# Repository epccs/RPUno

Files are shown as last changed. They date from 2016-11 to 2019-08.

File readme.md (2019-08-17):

# RPUno 

From <https://github.com/epccs/RPUno/>

## Overview

A general purpose ATmega328p controller board with level shift IO and current sources that operate over the wide input voltage range.

The bare metal microcontroller on this board is the same as an Arduino Uno, I use it to evaluate the examples. Normally C is my preference so converting Arduino's C++ into C adds some overhead, the toolchain supports both but find fewer surprises with C. The toolchain is available on most Linux distributions, a Raspberry Pi makes a nice remote computer and can handle networking services robustly. I use SSH to log in to the remote Raspberry Pi and then I can pull updates from GitHub and run the "Makefile" rules that compile and upload the firmware. The mezzanine board [RPUadpt] or [RPUpi] can be used to add a multidrop serial (rpubus). This controller can turn off its shield VIN pin to power down the Raspberry Pi on RPUpi.

[RPUadpt]: https://github.com/epccs/RPUadpt
[RPUpi]: https://github.com/epccs/RPUpi

[Forum](https://rpubus.org/bb/viewforum.php?f=6)

[HackaDay](https://hackaday.io/project/12784-rpuno)

## Status

Note: bootloader speed has changed from 115.2k to 38.4k bps due to upload errors with the new transceiver on RPUpi^4. Command line serial speed was changed to 38.4k bps some time ago. I have no clue how the bootload upload was working.



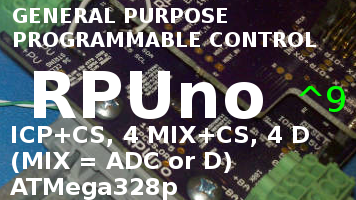
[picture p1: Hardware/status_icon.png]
Status


[Options](./Hardware#bill-of-materials)

## [Hardware](./Hardware)

Hardware files and notes for referance.

## Example with RPU BUS

This example shows a multidrop serial bus that has several microcontroller boards connected to a single Raspberry Pi computer. Linux on the single board computer controls a hardware UART (/dev/ttyAMA0) that has serial lines connected to a transceiver and its differential pairs. The remote boards have a [RPUadpt] mezzanine board and CAT5 cable daisy-chain between them. 

[Irrigate7]: https://github.com/epccs/Irrigate7

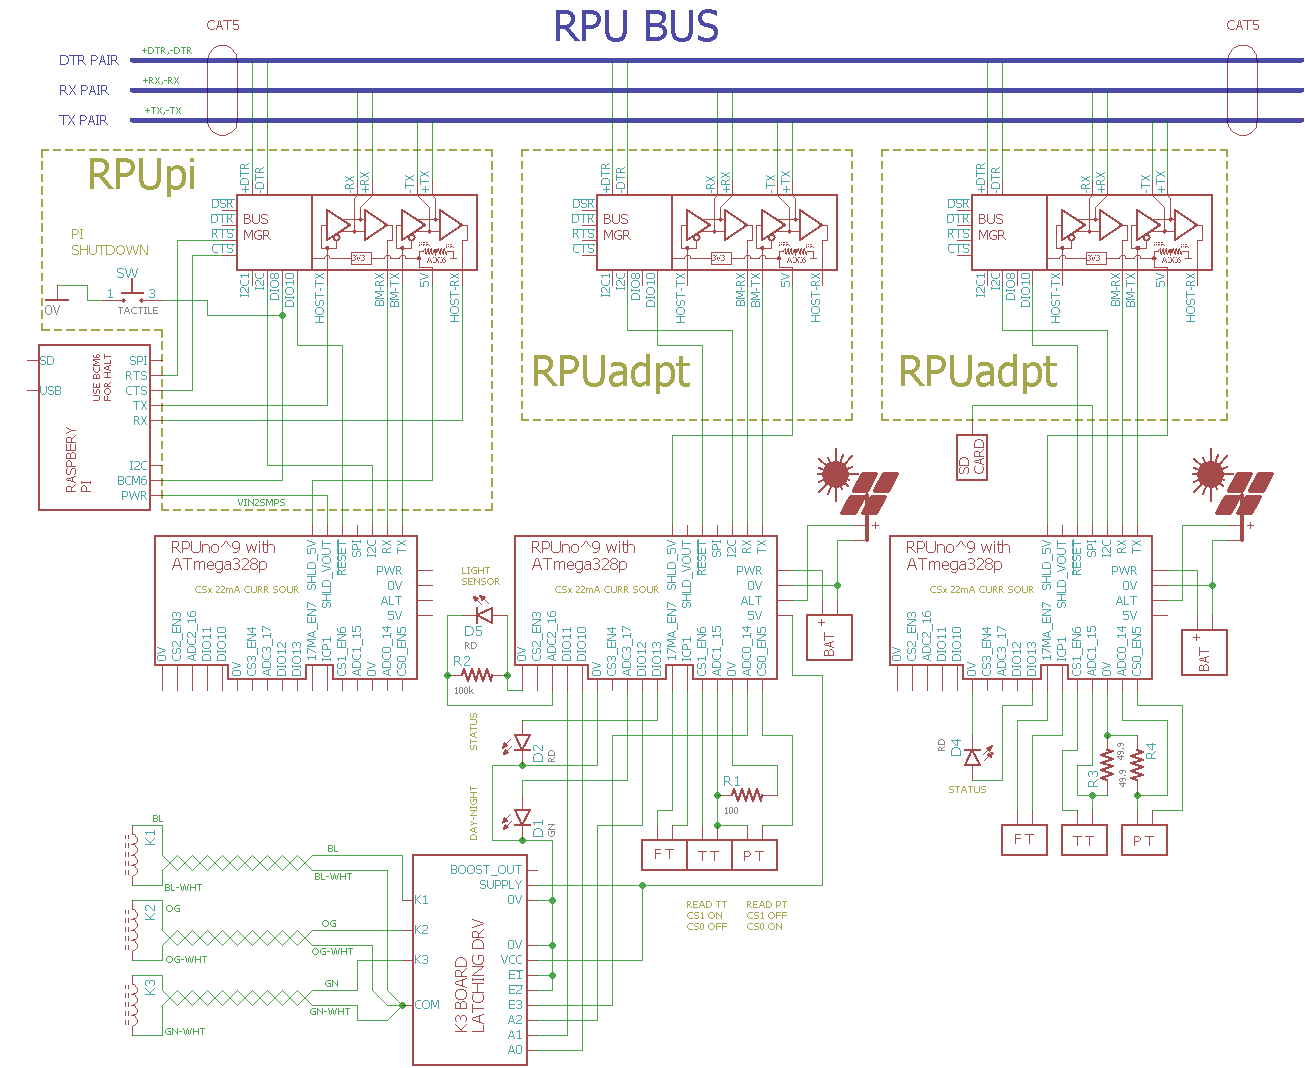
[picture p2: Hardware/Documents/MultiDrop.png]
MultiDrop RPUno MultiDrop


The transceivers are automatically activated, so common serial programs (e.g. avrdude, PySerial, picocom, and UART libraries) work without modification, but care must be taken to ensure only one controller answeres a host command. Each mezzanine board has a bus manager that is used to disconnect all the serial devices when the host connects, only the bootload target controller is connected. The host tells the manager what target to bootload over I2C (either using the local target controller or directly with 328pb second I2C interface). When the target runs its application and reads the bus address over I2C from the manager the manager broadcast a normal mode state that causes all the managers with valid controllers to connect to the serial lines.

I rely on a Command Line Interface (CLI) to the controllers. The CLI responds to commands terminated with a newline (inspired by console), press enter (which sends a newline) to start a command. The command includes an address with the first two bytes, but echo starts after the second byte is sent. The first byte will cause any transmitting device to stop and dump its outgoing buffer which prevents collisions in the data from the controllers to the host. The command length is also limited to allow the use of optimized buffer size.

As a short example, I'll connect with SSH (e.g. from a Windows 1809 build) to a Raspberry Pi Zero board. These machines have matching usernames, with configured SSH keys and known host file from a previous session. Once on the armv61 machine, I use picocom to interact with two different control boards. They are on the same serial bus at addresses '/1' and '/0' (note that ASCII '1' is 0x31, and ASCII '0' is 0x30, so they have an address that looks good on picocom but is probably not what was expected).

```
C:\Users\rsutherland>ssh pi1.local
Linux pi1 4.14.79+ #1159 Sun Nov 4 17:28:08 GMT 2018 armv6l

The programs included with the Debian GNU/Linux system are free software;
the exact distribution terms for each program are described in the
individual files in /usr/share/doc/*/copyright.

Debian GNU/Linux comes with ABSOLUTELY NO WARRANTY, to the extent
permitted by applicable law.
Last login: Sat Feb 16 12:24:59 2019 from 192.168.4.6
rsutherland@pi1:~ $ picocom -b 38400 /dev/ttyAMA0
picocom v1.7

port is        : /dev/ttyAMA0
flowcontrol    : none
baudrate is    : 38400
parity is      : none
databits are   : 8
escape is      : C-a
local echo is  : no
noinit is      : no
noreset is     : no
nolock is      : no
send_cmd is    : sz -vv
receive_cmd is : rz -vv
imap is        :
omap is        :
emap is        : crcrlf,delbs,

Terminal ready
/0/id?
{"id":{"name":"NightLight","desc":"RPUno (14140^9) Board /w atmega328p","avr-gcc":"5.4.0"}}
/1/id?
{"id":{"name":"AmpHr","desc":"RPUlux (17323^2) Board /w atmega328p","avr-gcc":"5.4.0"}}
Ctrl-a,Ctrl-x 
Thanks for using picocom
rsutherland@pi1:~ $ exit
logout
Connection to pi1.local closed.

C:\Users\rsutherland>
```

At present, I'm using [I2Cdebug] to set the manager bootload address. 

[I2Cdebug]: ./i2c-debug

## AVR toolchain

The core files for this board are in the /lib folder. Each example has its files and a Makefile in its own folder. The toolchain packages that I use are available on Ubuntu and Raspbian. 

```
sudo apt-get install make git gcc-avr binutils-avr gdb-avr avr-libc avrdude
git clone https://github.com/epccs/RPUno
```

packages on ubuntu are from Debain

* [gcc-avr](https://packages.ubuntu.com/search?keywords=gcc-avr)
* [binutils-avr](https://packages.ubuntu.com/search?keywords=binutils-avr)
* [gdb-avr](https://packages.ubuntu.com/search?keywords=gdb-avr)
* [avr-libc](https://packages.ubuntu.com/search?keywords=avr-libc)
* [avrdude](https://packages.ubuntu.com/search?keywords=avrdude)

The repository of binutils-avr for Debian is at

https://salsa.debian.org/debian/binutils-avr

The upstream where it was started from is 

https://www.gnu.org/software/binutils/

I don't see any AVR stuff in the upstream. Atmel must have forked it, and Debian is just patching critical material on the fork. Sadly I get the idea that these build tools are the last thing Microchip wants to mess with, I do not blame them it is a cluster, but it could be improved if they would start a public Github or Gitlab repository for these tools so I could have a place to contribute. Ideally, these updates would be added to the upstream, but I suspect that is not practical. Arduino uses these tools also, but they mainly want responsibility for there IDE. 

I place a [Bootloader] on the bare metal microcontroller with a fuse step and a step that uploads using an ISP tool. 

[Bootloader]: https://github.com/epccs/RPUno/tree/master/Bootloader

```
cd RPUno/Bootloader
# note /dev/ttyACM0 is my ICSP tool.
make fuse
make isp
```

The other applications are loaded through the bootloader using the host serial port. Note that the fuse cannot be changed with the bootloader thus reducing user issues with an application upload.

```
cd ~/RPUno/Adc
# note /dev/ttyUSB0 is my FTDI USBuart, and /dev/ttyAMA0 is my Raspberry Pi
make bootload
```

The software is a guide, it is in C because that is my preference for microcontrollers. If you want additional software please add a Github issue to this repository where we can discuss it. 

## Continuous Integration

Continuous Integration (CI) is the practice of automatically compiling and testing each time the mainline source is updated (e.g. git push). Travis CI is using a version of Ubuntu as there host environment for doing the test build. The build machine allows pulling in any packages I want including the AVR cross compiler. I don't do anything fancy, just run make. A rule like "make test" could be used if the test build machine had hardware connected (e.g. "make bootload" and then "make test") to the machine, but that is not practical in the foreseeable future. This was fairly simple to set up for Travis because the ATmega328p was in production at the time the Ubuntu toolchain was done.

[https://travis-ci.org/epccs/RPUno](https://travis-ci.org/epccs/RPUno)

Update: Travis has Ubuntu [Xenial] 16.04.

[Xenial]: https://docs.travis-ci.com/user/reference/xenial/

## Arduino IDE with Arduino 328p Core

The Arduino [IDE] can use the [Uno's AVR core] files that are included (my [core] files are C rather than C++), just remember to look at the schematic to see how the "Uno" is connected.  I do not use the Arduino IDE or C++ (I am a hardware designer,.and have limited intrest in software).

[IDE]: https://www.arduino.cc/
[Uno's AVR core]: https://github.com/arduino/ArduinoCore-avr
[core]: https://github.com/epccs/RPUno/tree/master/lib

## Visual Studio Code

VSC is one of the editors I use, and it is happy with Makefiles. The feature I like most is [IntelliSense], which is configured with JSON files in [.vscode]. 

[IntelliSense]: https://code.visualstudio.com/docs/editor/intellisense
[.vscode]: https://github.com/epccs/RPUno/tree/master/.vscode

The best way to use VSC with GCC (avr-gcc) is in an environment that just works, for me that is Linux, so I can enable [WSL] and install Ubuntu and then use the [Remote WSL].

[WSL]: https://docs.microsoft.com/en-us/windows/wsl/install-win10
[Remote WSL]: https://code.visualstudio.com/docs/remote/wsl

or I can install Linux on a 64bit x86 machine and use [Remote SSH].

[Remote SSH]: https://code.visualstudio.com/docs/remote/ssh

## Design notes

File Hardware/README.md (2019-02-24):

# Hardware

## Overview

ATmega328p based controller board with options for DIN mounts and 3.5mm spaced through-hole for user connections and headers. Eight level shifted (same as VIN range) digital I/O (10, 11, 12, 13, 14*, 15*, 16*, 17*), the last four (*) are analog channels (0, 1, 2, 3). Four 22mA current source used with loop sensors are available with enables (5, 6, 3, 4). One 17mA current source for a pulse sensor and it has an enable (7). ICP1 is pulled down when enough current (>7mA) arrives from the pulse sensor. Alternate power input may be enabled (9), and power to the shield VIN pin may be disabled (2). Power with 7 thru 36V DC.

The ATmega328p can be programmed with the GCC based toolchain for AVR found in Debian packages (it is available on, Ubuntu, Raspbian, Mac via brew, Windows via Windows Subsystem for Linux). Bootloader options include [optiboot] and [xboot]. Serial bootloaders cannot change the hardware fuse setting which reduces the occurrence of accidentally bricking the controller (I recommend using a serial bootloader during application development). Note that [optiboot] clears the watchdog so it will not get stuck in a watchdog loop.

[optiboot]: https://github.com/Optiboot/optiboot
[xboot]: https://github.com/alexforencich/xboot

## Inputs/Outputs/Functions

```
        Toolchain: gcc-avr binutils-avr gdb-avr avr-libc avrdude
        Wide input power range from 7..36V DC
        High side current sense on input power connected to ADC6.
        Input power voltage is divided down and connected to ADC7.
        Eight digital input/outputs (10,11,12,13,14*,15*,16*,17*) with level conversion.
        Four of the DIO may be used for ADC (*) channels 0..3 (ADC0,ADC1,ADC2,ADC3)
        Four 22mA current sources with enable (3,4,5,6).
        One 17mA current source with enable (7).
        Power to the shield VIN pin may be disabled (2).
        Alternate power input may be enabled (9).
        MCU power (+5V) is converted with an SMPS from the 7..36V input power.
```

## Uses

```
        General Purpose Control for Automation
            Bare Matal (e.g. infinite main loop checks inputs, performs algorithm, and writes outputs)
        Data Acquisition using Capture Hardware (ICP1).
            Flow Meter
            Rotating Hardware
            Pulse Output Temperature Sensors
            Pulse Output Capacitance Sensors
        Automation
            Shield VIN pin can power down a Raspberry Pi on the RPUpi shield.
            A current source may string through inputs of multiple Solid State Relays to control multi-phase power.
            Program in C with an open source toolchain (e.g. GCC, avrdude...).
```

## Notice

```
        ADC4 and ADC5 are used for I2C exclusively and not routed to the analog header.
        AREF from ATmega328p is not routed to the header.
        3V3 is not present on the board, the header pin is not connected.
```

# Table Of Contents

1. [Status](#status)
2. [Design](#design)
3. [Bill of Materials](#bill-of-materials)
4. [Assembly](#assembly)
5. [How To Use](#how-to-use)

# Status

Status RPUno Status

```
        ^9  Done: Design, Layout, BOM, Review*, Order Boards, Assembly, Testing,
            WIP: Evaluation.
            Todo: 
            *during review the Design may change without changing the revision.
            Remove ICP1 10mA pull-up
            Replace digital curr sources with CS2 and CS3
            Replace IO3 and IO4 with ADC2 and ADC3
            Swap MOSI (IO11) with ADC3
            Use IO3 and IO4 to enalbe 22mA CS2 and CS3
            Add level shift to ADC0 and ADC1 so they can be used as digital IO
            Add bootload port (e.g. for Adafruit Friend)
            Add alternate power input (e.g. disconnect a solar pannel to stop charge)
            Pull-down IO9 and 100k ohm on zener to make sure alt power is off at init

        ^8  Done: Design, Layout, BOM, Review*, Order Boards,
            all boards scraped, no assembly done

        ^7  Done: Design, Layout, BOM, Review*, Order Boards, Assembly, Testing,
            WIP: Evaluation.
            use an ESD_NODE like Irrigate7.
            don't turn off the current source used with digital outputs since the digital IO's can do that. 
            DIO protection resistor (change 182 Ohm to 127 Ohm)
            remove LT3652 and reduce size of board.
            add an IDC connector for everything that was used with LT3652 (5,6,7,ADC2,ADC3).
            add JSK plug for I2C
            location: 2017-11-1 reflow oven.

        ^6  two test units (T1,T2) made, four units made to see if anyone is intrested.
            location: 2017-3-24 T1^6 damaged MCU while taking power example image.
                    2017-3-25 T2^6 using on test bench.
                    2017-6-12 T1^6 replaced MCU from a scrped RPUno^4 and tested again.
                    2017-7-19 T2^6 + RPUadpt^5 in SEncl NightLight testing.
                    2017-8-26 T2^6 NightLight ended, unit is in an enclosure with battey but is not in use.
                    2018-4-15 T1 and T2 scap.

        ^5  only unit of this version made
            location: 2016-12-18 Test Bench /w an RPUpi^1, start power management testing
                    2017-1-1 had ADC7 parts (and BOM) changed to measre battery.
                    2017-1-5 had ADC6 hacked to measure raw PV.
                    2017-2-4 moved to SWall Encl /w K3^1, RPUadpt^4, SLP003-12U, 12V battery.
                    2017-3-19 remove 10k thermistor which was used by  LT3652 to turn off chrg when over 40 C
                    2017-4-17 running Solenoid fw, @ SWall Encl, Update K3^2, Update RPUadpt^5, SLP003-12U, 12V battery.
```

Debugging and fixing problems i.e. [Schooling](./Schooling/)

Setup and methods used for [Evaluation](./Evaluation/)

# Design

The board is 0.063 thick, FR4, two layer, 1 oz copper with ENIG (gold) finish.

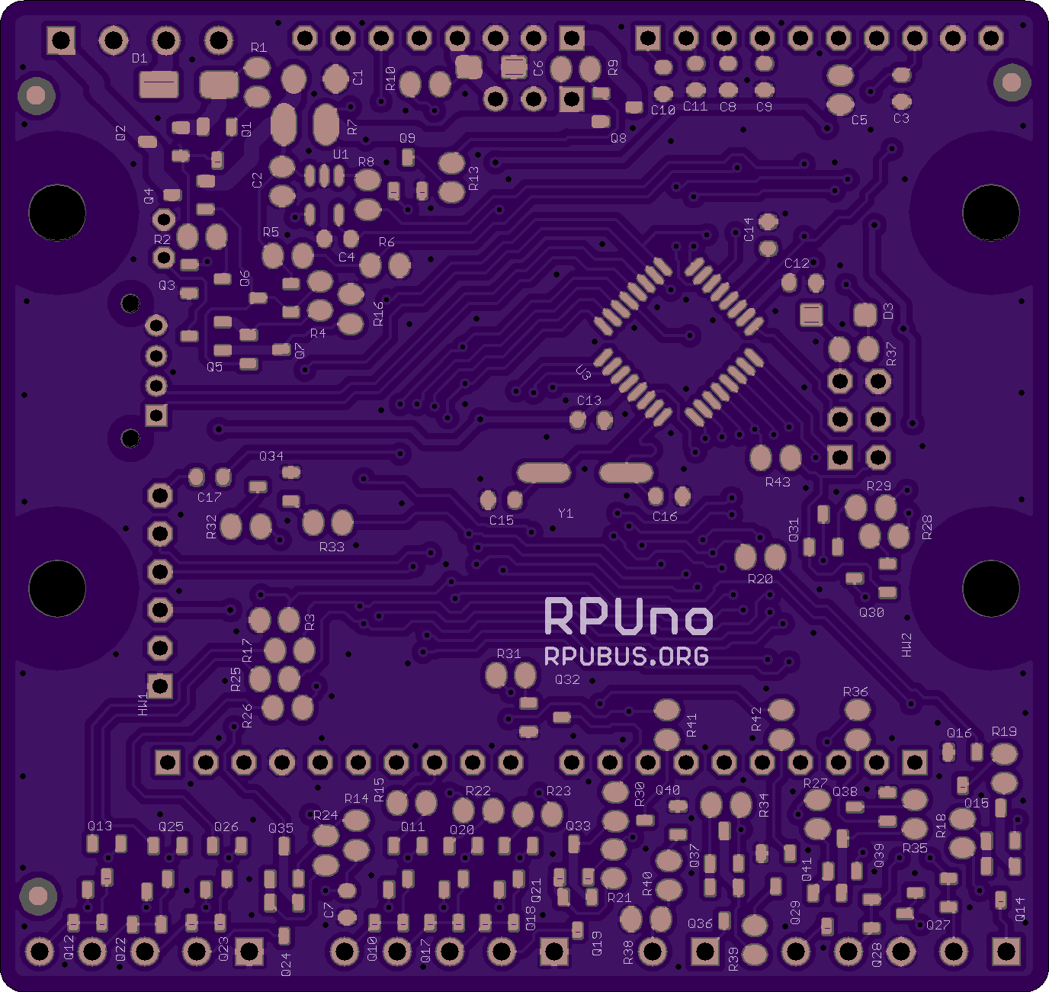
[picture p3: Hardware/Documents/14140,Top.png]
Top RPUno Top

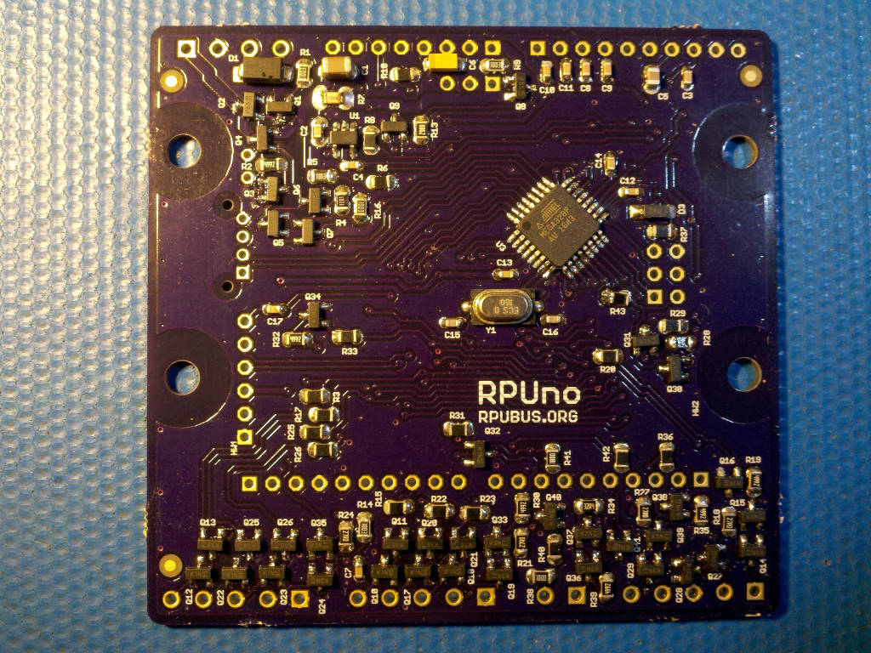
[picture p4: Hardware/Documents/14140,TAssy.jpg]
TAssy RPUno Top Assy

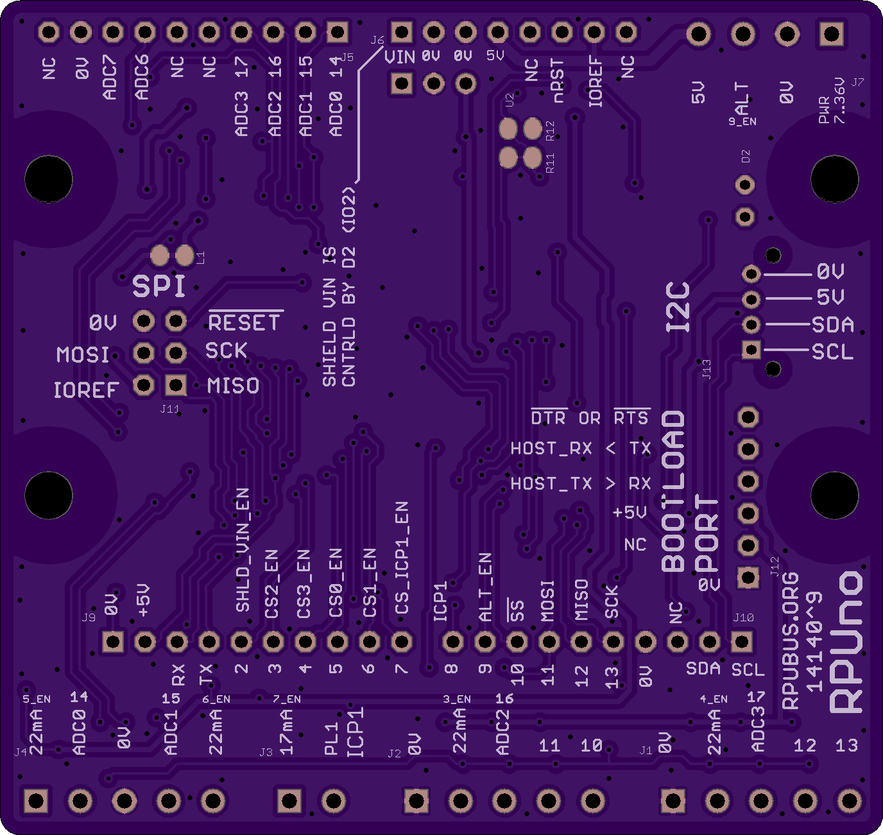
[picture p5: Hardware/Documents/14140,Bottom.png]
Bottom RPUno Bottom

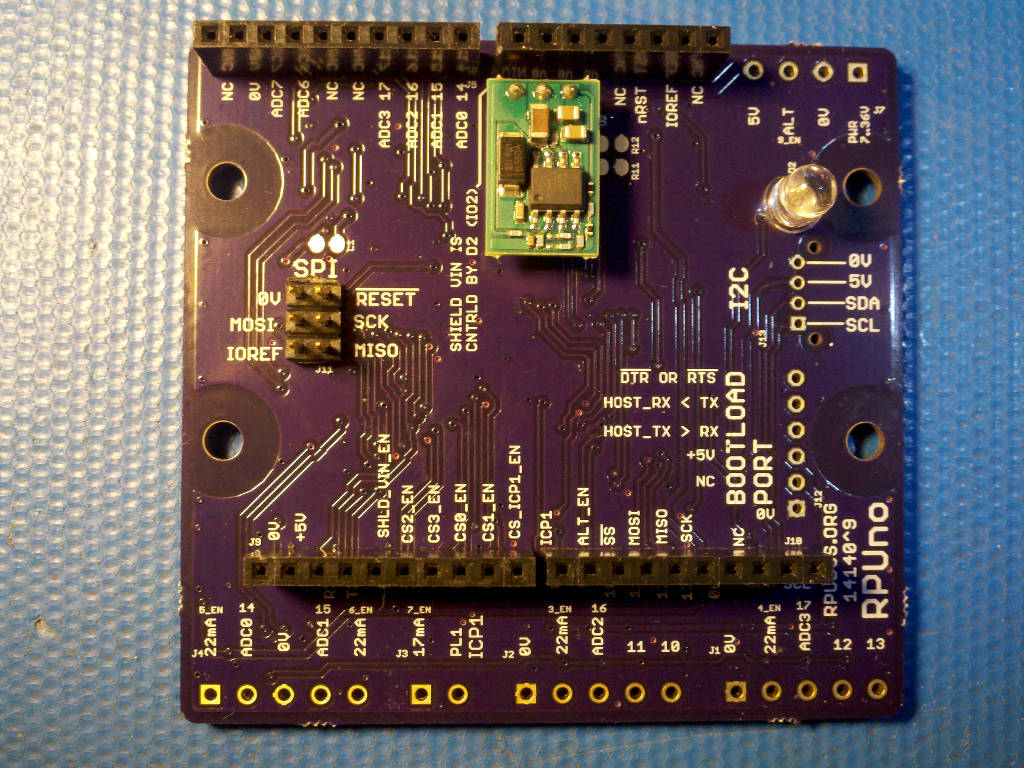
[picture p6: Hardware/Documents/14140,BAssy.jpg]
BAssy RPUno Bottom Assy


## Electrical Parameters

```
Power Voltage: 7 thru 36V
```

## Mounting

```
        DIN rail
```

## Electrical Schematic

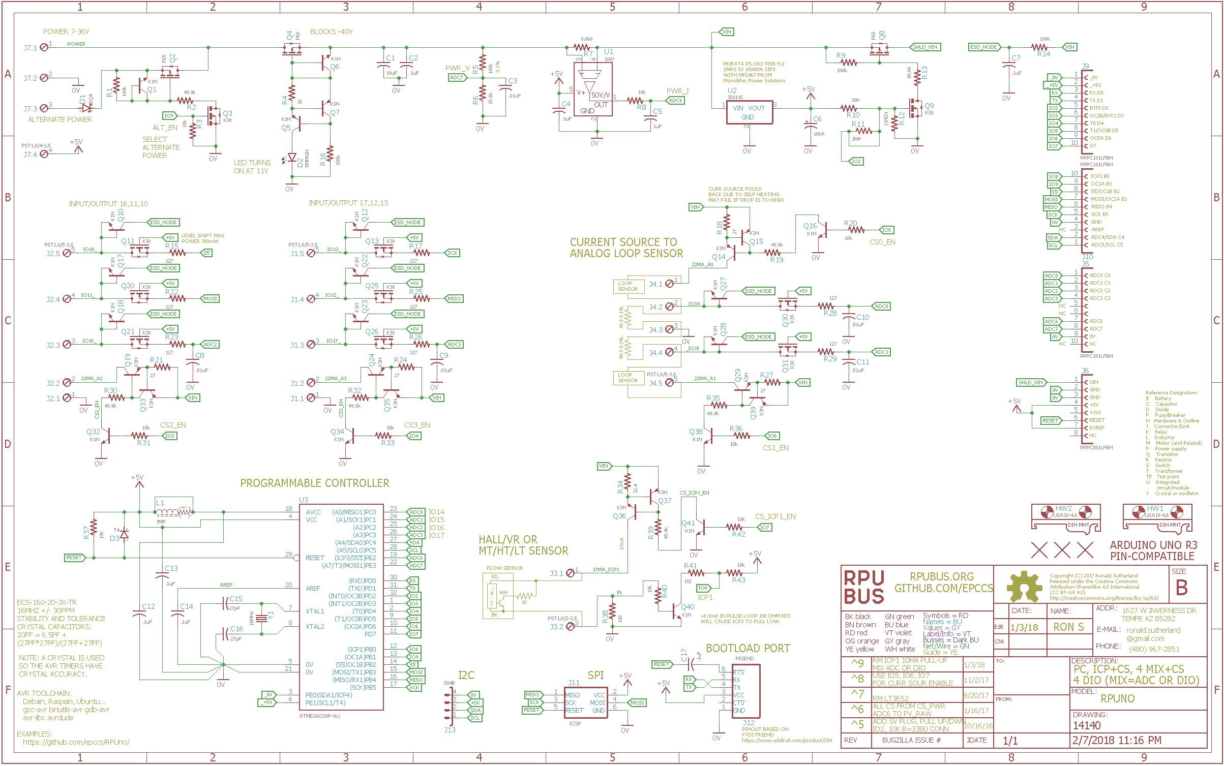
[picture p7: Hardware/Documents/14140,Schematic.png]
Schematic RPUno Schematic


## Testing

Check correct assembly and function with [Testing](./Testing/)

# Bill of Materials

The BOM is a CVS file, import it into a spreadsheet program like LibreOffice Calc (or Excel), or use a text editor.

Option | BOM's included
----- | ----- 
A. | [BRD] 
M. | [BRD] [SMD] [HDR] 
W. | [BRD] [SMD] [HDR] [PLUG]
Z. | [BRD] [SMD] [HDR] [PLUG] [DIN]

[BRD]: ./Design/14140BRD,BOM.csv
[SMD]: ./Design/14140SMD,BOM.csv
[HDR]: ./Design/14140HDR,BOM.csv
[PLUG]: ./Design/14140PLUG,BOM.csv
[DIN]: ./Design/14140DIN,BOM.csv

[Order Form](https://rpubus.org/Order_Form.html)

# Assembly

## SMD

The board is assembled with CHIPQUIK no-clean solder SMD291AX (RoHS non-compliant). 

The SMD reflow is done in a Black & Decker Model NO. TO1303SB which has the heating elements controlled by a Solid State Relay and an ATMega328p loaded with this [Reflow] firmware.

[Reflow]: https://github.com/epccs/RPUno/tree/master/Reflow

# How To Use

The application should have a wiring diagram to show the setup.

## Solar

Trickle charging a battery can be done directly through a diode when the PV source is less than or about .02C (e.g. 200mA into a 10AHr battery). This means that the need for a charge controller depends on if the user wants to size the PV and battery storage for trickle or quick charging (i.e. >0.02C). When I use an SLP003-12U panel that charges at less than 200mA and a 10AHr AGM battery with a diode that blocks dark current no charge controller is needed. 

## Input Power LC 

Input wiring can have inductance that oscilates as an [LC circuit] with the input capacitor. The problem can show up when the SMPS has a frequancy component that drives the oscilation. There are many ways to deal with the issue, a few examples include twisting the input power wires to lower there inductance, adding a ferite to dampen the oscilation, adding a bypass or two along the line to shift the oscilation nodes.

[LC circuit]: https://en.wikipedia.org/wiki/LC_circuit

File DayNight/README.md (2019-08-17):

# Day-Night State Machine

## Overview

Use a red LED's photovoltaic voltage to approximately tell if it is day or night. 

Note: use the Day_AttachDayWork() and Night_AttachWork() functions to register a callback that will be run at the start of each day. This framework is how I debuged the day-night stat machine.

## Wiring Needed for Light Sensor

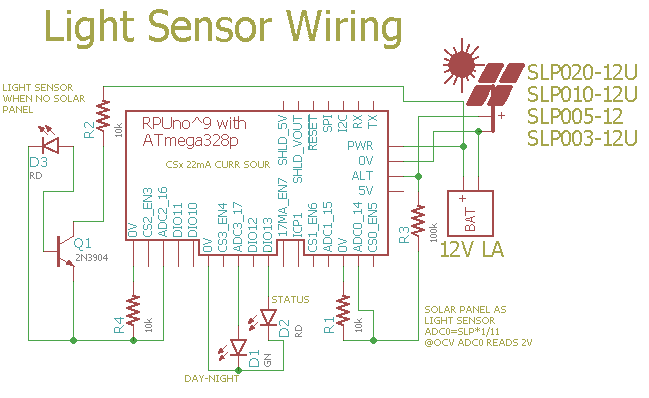
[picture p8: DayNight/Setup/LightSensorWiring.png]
Wiring


The LED is a CREE C503B-RCN-CW0Z0AA1. The LED works somewhat like a solar cell but it develops up to 1.6V with red light and shorter wavelengths. The LED will act as a current source to the NPN transistor base which will then do [common emitter current gain] which can be measured with ADC1 on R4. Over a very short time, the sun will move through the LED focus. Adding a diffuser reduces this effect and extends the day/night debounce to more appropriate times.

[common emitter current gain]: https://en.wikipedia.org/wiki/Bipolar_junction_transistor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

With a solar panel use a [voltage divider].

[voltage divider]: https://en.wikipedia.org/wiki/Voltage_divider

## Firmware Upload

With a serial port connection (see BOOTLOAD_PORT in Makefile) and optiboot installed on the RPUno run 'make bootload' and it should compile and then flash the MCU.

``` 
sudo apt-get install make git gcc-avr binutils-avr gdb-avr avr-libc avrdude
git clone https://github.com/epccs/RPUno/
cd /RPUno/DayNight
make bootload
...
avrdude done.  Thank you.
``` 

Now connect with picocom (or ilk). 

``` 
#exit is C-a, C-x
picocom -b 38400 /dev/ttyUSB0
``` 

# Commands

Commands are interactive over the serial interface at 38400 baud rate. The echo will start after the second character of a new line. 

## /\[rpu_address\]/\[command \[arg\]\]

rpu_address is taken from the I2C address 0x29 (e.g. ../Uart/id.h get_Rpu_address() ). The value of rpu_address is used as a character in a string, which means don't use a null value (C strings are null terminated), but the ASCII value for '1' (0x31) is easy and looks nice.

The STATUS_LED is bliked fast (twice per second) if the I2C address is not found, also the rpu_address defaults to '0'. 

Commands and their arguments follow.

## /0/id? \[name|desc|avr-gcc\]

Identify is from ../Uart/id.h Id().

``` 
/1/id?
{"id":{"name":"DayNight","desc":"RPUno Board /w atmega328p and LT3652","avr-gcc":"4.9"}}
```

## /0/day?

Report status of the state machine.

``` 
/1/day?
{"day_state":"DAY"}
... 11 hr
{"day_state":"DAY"}
{"day_state":"EVE"}
... 15 min
{"day_state":"NEVT"}
TurnOnLED's
{"day_state":"NGHT"}
... 12 hr
{"day_state":"NGHT"}
{"day_state":"MORN"}
... 15 min
{"day_state":"DEVT"}
WaterTheGarden
{"day_state":"DAY"}
... 20 hr (e.g. using an indoor lamp)
{"day_state":"DAY"}
{"day_state":"FAIL"}
```

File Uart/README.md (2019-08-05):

# AVR Interrupt-Driven UART with stdio redirect

## Overview

Uart is an interactive command line program that demonstrates stdio redirect of a minimalized interrupt-driven UART for AVR. 

## Firmware Upload

With a serial port connection (see BOOTLOAD_PORT in Makefile) and optiboot installed on the RPUno run 'make bootload' and it should compile and then flash the MCU.

``` 
sudo apt-get install make git gcc-avr binutils-avr gdb-avr avr-libc avrdude
git clone https://github.com/epccs/RPUno/
cd /RPUno/Uart
make bootload
...
avrdude done.  Thank you.
``` 

Now connect with picocom (or ilk).

``` 
#exit is C-a, C-x
picocom -b 38400 /dev/ttyUSB0
``` 

# Commands

Commands are interactive over the serial interface at 38400 baud rate. The echo will start after the second character of a new line. 

## /\[rpu_address\]/\[command \[arg\]\]

rpu_address is taken from the I2C address 0x29 (e.g. get_Rpu_address() which is included form ../lib/rpu_mgr.h). The value of rpu_address is used as a character in a string, which means don't use a null value (C strings are null terminated) as an adddress. The ASCII value for '1' (0x31) is easy and looks nice, though I fear it will cause some confusion when it is discovered that the actual address value is 49.

Commands and their arguments follow.

## /0/id? \[name|desc|avr-gcc\]

identify 

``` 
/0/id?
{"id":{"name":"Uart","desc":"RPUno Board /w ATmega328p and LT3652","avr-gcc":"4.9"}}
```

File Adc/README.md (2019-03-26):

# Analog-to-Digital Converter

## Overview

Adc is an interactive command line program that demonstrates control of an Analog-to-Digital Converter from pins PC0 through PC7 on an ATmega328p. 

A customized library routine is used to operate the AVR's ADC, it has an ISR that is started with the enable_ADC_auto_conversion function to read the channels in a burst (free running is also an option). In this case, the bare metal loop starts the burst at timed intervals of 200 milliseconds. The ADC clock runs at 125kHz and it takes 25 of its clocks to complete a conversion, thus a burst takes 1.6 milliseconds (e.g. 8*25*(1/125000)) to scan the eight channels. The ADC is turned off after each burst so some power is saved, but barely enough to bother.

The ADMUX register is used when selecting ADC channels.  The analog channel has nothing to do with the digital pin number used by [Wiring]. The pin used by ADC channel 0 has been assigned the number 14 for the digital Wiring functions (e.g. pinMod, digitalRead...), however for analogRead the ADC channel number is used.

[Wiring]: https://arduinohistory.github.io/

# EEPROM Memory map 

A map of calibration valuses in EEPROM. 

```
function            type        ee_addr:
id                  UINT16      30
ref_extern_avcc     UINT32      32
ref_intern_1v1      UINT32      36
```

The AVCC pin is used to power the analog to digital converter and is also selected as a reference. On RPUno the AVCC pin is powered by a switchmode supply that can be measured to use as a calibrated reference.

The internal 1V1 bandgap is not trimmed by the manufacturer, so it needs to be measured. However, once it is known it is a better reference than AVCC.

[SelfTest] loads calibration values for references in EEPROM.

[SelfTest]: https://github.com/epccs/RPUno/tree/master/SelfTest

# Firmware Upload

With a serial port connection (see BOOTLOAD_PORT in Makefile) and optiboot installed on the RPUno run 'make bootload' and it should compile and then flash the MCU.

``` 
sudo apt-get install make git gcc-avr binutils-avr gdb-avr avr-libc avrdude
git clone https://github.com/epccs/RPUno/
cd /RPUno/Adc
make bootload
...
avrdude done.  Thank you.
``` 

Now connect with picocom (or ilk).

``` 
#exit is C-a, C-x
picocom -b 38400 /dev/ttyUSB0
``` 

or log the terminal session

``` 
script -f -c "picocom -b 38400 /dev/ttyUSB0" stuff.log
``` 

# Commands

Commands are interactive over the serial interface at 38400 baud rate. The echo will start after the second character of a new line. 

## /\[rpu_address\]/\[command \[arg\]\]

rpu_address is taken from the I2C address 0x29 (e.g. get_Rpu_address() which is included form ../lib/rpu_mgr.h). The value of rpu_address is used as a character in a string, which means don't use a null value (C strings are null terminated) as an adddress. The ASCII value for '1' (0x31) is easy and looks nice, though I fear it will cause some confusion when it is discovered that the actual address value is 49.

Commands and their arguments follow.

## /0/id? \[name|desc|avr-gcc\]

identify 

``` 
/1/id?
{"id":{"name":"Adc","desc":"RPUno (14140^9) Board /w atmega328p","avr-gcc":"5.4.0"}}
```

##  /0/analog? 0..7\[,0..7\[,0..7\[,0..7\[,0..7\]\]\]\]    

Analog-to-Digital Converter reading from up to 5 ADMUX channels. The reading repeats every 60 Seconds until the Rx buffer gets a character. On RPUno channel 7 is the input voltage (PWR_V), channel 6 is the input current (PWR_I), channel 3, 2,  1, and 0 inputs can read up to 3.5V (higher voltages are blocked by a level shift).  Note channel 4 and 5 are used for I2C on RPUno.

``` 
/1/analog? 6,7
{"PWR_I":"0.000","PWR_V":"12.51"}
/1/analog? 0,1,2,3
{"ADC0":"1.38","ADC1":"2.83","ADC2":"0.72","ADC3":"0.61"}
/1/analog? 4,5
{"ADC4":"SDA","ADC5":"SCL"}
```

Values are from floating ADC channels. PWR_I is AVCC referance (SelfTest uses the 1V1 band gap).

The value reported is based on the avcc referance value which is saved in EEPROM, see bellow.

##  /0/avcc 4500000..5500000

Calibrate the AVCC reference in microvolts.

``` 
/1/avcc 5006500
# do this with the SelfTest
``` 

##  /0/onevone 900000..1300000

Set the 1V1 internal bandgap reference in microvolts.

```
/1/onevone 1100000
# do this with the SelfTest
``` 

The SelfTest will calculate this value when it is ran based on the AVCC value compiled into source.

##  /0/reftoee

Save the reference in static memory to EEPROM.

```
/1/reftoee
# do this with the SelfTest
```

##  /0/reffrmee

Load the reference from EEPROM into static memory.

```
/1/reffrmee
{"REF":{"extern_avcc":"5.0065","intern_1v1":"1.0733",}}
```

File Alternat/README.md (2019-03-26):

# Alternate Power Input

## Overview

Alternate power input is used to send current from a solar panel into a battery. 

The alternate power source needs to act as a current source, and the main power source needs to act like a battery. Do not attempt this with a bench power supply as the main power input. When the alternate power is enabled it must current limit and then charge the battery.

The DayNight state machine is used, it has two events that run a registered callback function. The day event turns on the alternate power input, while the night event turns it off. Adc channels are measured with a burst of interrupts that occurs every 100 millis. Near the time of the Adc burst, the mux channel PWR_V which is connected to an input voltage divider (a 1% 15.8k and a 0.1% 100k) is checked. This is more or less the battery voltage so can be used to turn off the Alternate power input when the battery has reached a limit, and then turn it back on when the voltage drops.

The hardware for this lacks training wheels, it is going to take some time to refine these ideas. The target battery is lead acid, this method fails with other types. 

## Wiring Needed

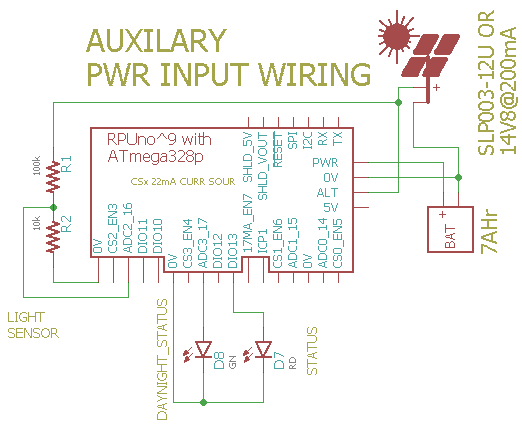
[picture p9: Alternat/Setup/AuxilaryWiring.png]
Wiring


# Firmware Upload

With a serial port connection (see BOOTLOAD_PORT in Makefile) and optiboot installed on the RPUno run 'make bootload' and it should compile and then flash the MCU.

``` 
sudo apt-get install make git gcc-avr binutils-avr gdb-avr avr-libc avrdude
git clone https://github.com/epccs/RPUno/
cd /RPUno/Alternat
make bootload
...
avrdude done.  Thank you.
``` 

Now connect with picocom (or ilk).

``` 
#exit is C-a, C-x
picocom -b 38400 /dev/ttyUSB0
``` 

# Commands

Commands are interactive over the serial interface at 38400 baud rate. The echo will start after the second character of a new line. 

## /\[rpu_address\]/\[command \[arg\]\]

rpu_address is taken from the I2C address 0x29 (e.g. get_Rpu_address() which is included form ../lib/rpu_mgr.h). The value of rpu_address is used as a character in a string, which means don't use a null value (C strings are null terminated) as an adddress. The ASCII value for '1' (0x31) is easy and looks nice, though I fear it will cause some confusion when it is discovered that the actual address value is 49.

Commands and their arguments follow.

## /0/id? \[name|desc|avr-gcc\]

identify 

``` 
/1/id?
{"id":{"name":"Alternat","desc":"RPUno (14140^9) Board /w atmega328p","avr-gcc":"5.4.0"}}
```

##  /0/alt

This will toggle the Alternat Power enable

``` 
/1/alt
{"alt":"ON"}
```

##  /0/altcnt?

This gives the number of times the charging limit was reached, it is a clue about how charged the battery is.

``` 
/1/altcnt?
{"alt_count":"2"}
``` 

Example with limit set at 13.6V and 180mA solar pannel and 18AHr AGM battery. 

``` 
/1/alt
{"alt_en":"ON"}
/1/altcnt?
{"alt_count":"0"}
/1/analog? 6,7
{"PWR_I":"0.019","PWR_V":"13.51"}
{"PWR_I":"0.019","PWR_V":"13.58"}
/1/altcnt?
{"alt_count":"1"}
/1/analog? 6,7
{"PWR_I":"0.017","PWR_V":"13.51"}
{"PWR_I":"0.017","PWR_V":"13.47"}
{"PWR_I":"0.017","PWR_V":"13.47"}
{"PWR_I":"0.017","PWR_V":"13.47"}
{"PWR_I":"0.017","PWR_V":"13.47"}
{"PWR_I":"0.017","PWR_V":"13.51"}
{"PWR_I":"0.017","PWR_V":"13.58"}
/1/altcnt?
{"alt_count":"2"}
/1/analog? 6,7
{"PWR_I":"0.017","PWR_V":"13.51"}
{"PWR_I":"0.017","PWR_V":"13.51"}
{"PWR_I":"0.017","PWR_V":"13.47"}
{"PWR_I":"0.017","PWR_V":"13.58"}
{"PWR_I":"0.017","PWR_V":"13.51"}
{"PWR_I":"0.017","PWR_V":"13.55"}
{"PWR_I":"0.017","PWR_V":"13.47"}
/1/altcnt?
{"alt_count":"3"}
```

## [/0/analog? 0..7\[,0..7\[,0..7\[,0..7\[,0..7\]\]\]\]](../Adc#0analog-0707070707)

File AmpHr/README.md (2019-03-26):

# Amp-Hour Counter

## Overview

Use ADC reading to Accumulate at timed intervals from a sense resistor. This is an interactive command line program that demonstrates how the ATmega328p can be used to track the discharge from a battery. 

[Adc]: ../Adc

# Firmware Upload

With a serial port connection (see BOOTLOAD_PORT in Makefile) and optiboot installed on the RPUno run 'make bootload' and it should compile and then flash the MCU.

``` 
sudo apt-get install make git gcc-avr binutils-avr gdb-avr avr-libc avrdude
git clone https://github.com/epccs/RPUno/
cd /RPUno/AmpHr
make bootload
...
avrdude done.  Thank you.
``` 

Now connect with picocom (or ilk). 

``` 
#exit is C-a, C-x
picocom -b 38400 /dev/ttyUSB0
``` 

or log the terminal session

``` 
script -f -c "picocom -b 38400 /dev/ttyUSB0" stuff.json
``` 

# Commands

Commands are interactive over the serial interface at 38400 baud rate. The echo will start after the second character of a new line. 

## /\[rpu_address\]/[command \[arg\]\]

rpu_address is taken from the I2C address 0x29 (e.g. get_Rpu_address() which is included form ../Uart/id.h). The value of rpu_address is used as a character in a string, which means don't use a null value (C strings are null terminated), but the ASCII value for '1' (0x31) is easy and looks nice, though I fear it will cause some confusion when it is discovered that the actual address value is 49.

Commands and their arguments follow.

## /0/id? \[name|desc|avr-gcc\]

identify 

``` 
/1/id?
{"id":{"name":"AmpHr","desc":"RPUno (14140^9) Board /w atmega328p","avr-gcc":"5.4.0"}}
```

##  /0/charge?

Report the discharge since the day-night state machine cleared the accumulation.

``` 
/1/charge?
{"CHRG_mAHr":"0.14","ACCUM_Sec":"44.78"}
/1/analog? 6,7
{"PWR_I":"0.012","PWR_V":"12.72"}
```

## [/0/analog? 0..7\[,0..7\[,0..7\[,0..7\[,0..7\]\]\]\]](../Adc#0analog-0707070707)

## [/0/pwm CH1..CH6,0..255](../Pwm#0pwm-ch1ch60255)

## [/0/pMod 14..16,INPUT|OUTPUT](../Digital#0pmod-1416inputoutput)

## [/0/dWrt 14..16,HIGH|LOW](../Digital#0dwrt-1416highlow)

## [/0/dTog 14..16](../Digital#0dtog-1416)

## [/0/dRe? 14..16](../Digital#0dre-1416)

## [/0/iscan?](../i2c-debug#0iscan)

## [/0/iaddr 0..127](../i2c-debug#0iaddr-0127)

## [/0/ibuff 0..255\[,0..255\[,0..255\[,0..255\[,0..255\]\]\]\]](../i2c-debug#0ibuff-02550255025502550255)

## [/0/ibuff?](../i2c-debug#0ibuff)

## [/0/iwrite](../i2c-debug#0iwrite)

## [/0/cs 0..3,ON|OFF](../CurrSour#0cs-01onoff)

## [/0/csp 0..0,ON|OFF](../CurrSour#0csp-00onoff)

## [/0/showstat ON|OFF](../CurrSour#0showstat-onoff)

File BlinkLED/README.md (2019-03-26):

# Makefile based non-blocking Blink

## Overview

Demonstration of General I/O, e.g. Blink an LED. 

Referance ATmega328 datasheet I/O-Ports

Also shows the UART core and how to redirect it to stdin and stdout, as well as some Python that sends an 'a' character to stop the LED from blinking. 

## Firmware Upload

With a serial port connection (see BOOTLOAD_PORT in Makefile) and optiboot installed on the RPUno run 'make bootload' and it should compile and then flash the MCU.

``` 
sudo apt-get install make git gcc-avr binutils-avr gdb-avr avr-libc avrdude
git clone https://github.com/epccs/RPUno/
cd /RPUno/BlinkLED
make bootload
...
avrdude done.  Thank you.
``` 

# Notes

pin_num.h was hacked from William Greiman work (https://github.com/greiman) into plain C, but it still looks a little like Wiring.

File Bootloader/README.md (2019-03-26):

# Serial Bootloader

## Overview

AVR microcontrollers are usually programmed through an In-circuit Serial Programmer (ICSP/ISP), however with this firmware loaded in your microcontroller programing can be done over a serial interface (TX/RX) without the ICSP programmer. This is called serial bootloading. 

Unfortunalty to install a serial bootloader requires an ICSP tool. Arduino has an [ArduinoISP] sketch that I load into a Arduino Uno to use as an ICSP tool.

[ArduinoISP]: https://github.com/arduino/Arduino/blob/master/build/shared/examples/11.ArduinoISP/ArduinoISP/ArduinoISP.ino

It is a two step process. First run "make fuse" which will unlock the boot flash section and set fuses (LOW, HIGH, EXTENDED). The changed fuse setting will switch operation form the internal oscilator to the exteranl crystal, if it is missing the MCU will be locked up. The second step is "make isp" which will load the bootloader and lock the boot flash section, which should prohibit the Store Program Memory (SPM) instruction from running in the boot flash section. 

    WARNING: programing these fuse valuse will lock up the MCU when the crystal is missing or damaged.

## Firmware Upload

With ISP tool connected.

``` 
sudo apt-get install make git gcc-avr binutils-avr gdb-avr avr-libc avrdude
git clone https://github.com/epccs/RPUno/
cd /RPUno/Bootloader
make fuse
...
avrdude done.  Thank you.
make isp
...
avrdude done.  Thank you.
``` 

The bootloader is from MiniCore
https://github.com/MCUdude/MiniCore

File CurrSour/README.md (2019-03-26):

# Current Source

## Overview

There are four 22mA current sources CS0..CS3 controlled with ATmega328p pins PD5, PD6, PD3, and PD4. There is one 17mA current source for ICP1 controlled with PD7.

# Firmware Upload

With a serial port connection (see BOOTLOAD_PORT in Makefile) and optiboot installed on the RPUno run 'make bootload' and it should compile and then flash the MCU.

``` 
sudo apt-get install make git gcc-avr binutils-avr gdb-avr avr-libc avrdude
git clone https://github.com/epccs/RPUno/
cd /RPUno/CurrSour
make bootload
...
avrdude done.  Thank you.
``` 

Now connect with picocom (or ilk).

``` 
#exit is C-a, C-x
picocom -b 38400 /dev/ttyUSB0
``` 

# Commands

Commands are interactive over the serial interface at 38400 baud rate. The echo will start after the second character of a new line. 

## /\[rpu_address\]/\[command \[arg\]\]

rpu_address is taken from the I2C address 0x29 (e.g. get_Rpu_address() which is included form ../lib/rpu_mgr.h). The value of rpu_address is used as a character in a string, which means don't use a null value (C strings are null terminated) as an adddress. The ASCII value for '1' (0x31) is easy and looks nice, though I fear it will cause some confusion when it is discovered that the actual address value is 49.

Commands and their arguments follow.

## /0/id? \[name|desc|avr-gcc\]

identify 

``` 
/1/id?
{"id":{"name":"CurrSour","desc":"RPUno (14140^9) Board /w atmega328p","avr-gcc":"5.4.0"}}
```

##  /0/cs 0..3,ON|OFF

Turn on (or off) 22mA current sources CS0..CS3

``` 
/1/cs 2,ON
{"PD3":"ON"}
/1/cs 2,OFF
{"PD3":"OFF"}
```

##  /0/csp 0,ON|OFF

Turn on (or off) 17mA current source for ICP1

``` 
/1/csp 0,ON
{"ICP1":"ON"}
/1/csp 0,OFF
{"ICP1":"OFF"}
```

##  /0/showstat ON|OFF

A current source can be used to show status, but it is not ON by default.

``` 
/1/showstat ON
{"SHOW":"ON"}
/1/showstat OFF
{"SHOW":"OFF"}
```

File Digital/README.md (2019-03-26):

# Digital Input/Output

## Overview

Digital is an interactive command line program that demonstrates control of the Digital input/output from ATmega328p pins PB2..PB5 (10..13) and PC0..PC3 (14..17).

## Firmware Upload

With a serial port connection (see BOOTLOAD_PORT in Makefile) and optiboot installed on the RPUno run 'make bootload' and it should compile and then flash the MCU.

``` 
sudo apt-get install make git gcc-avr binutils-avr gdb-avr avr-libc avrdude
git clone https://github.com/epccs/RPUno/
cd /RPUno/Digital
make bootload
...
avrdude done.  Thank you.
``` 

Now connect with picocom (or ilk).

``` 
#exit is C-a, C-x
picocom -b 38400 /dev/ttyUSB0
``` 

# Commands

Commands are interactive over the serial interface at 38400 baud rate. The echo will start after the second character of a new line. 

## /\[rpu_address\]/\[command \[arg\]\]

rpu_address is taken from the I2C address 0x29 (e.g. ../Uart/id.h get_Rpu_address() ). The value of rpu_address is used as a character in a string, which means don't use a null value (C strings are null terminated), but the ASCII value for '1' (0x31) is easy and looks nice, though I fear it will cause some confusion when it is discovered that the actual address value is 49.

The STATUS_LED is bliked fast (twice per second) if the I2C address is not found, also the rpu_address defaults to '0'. 

Commands and their arguments follow.

## /0/id? \[name|desc|avr-gcc\]

Identify is from ../Uart/id.h Id().

``` 
/1/id?
{"id":{"name":"Digital","desc":"RPUno (14140^9) Board /w atmega328p","avr-gcc":"5.4.0"}}
```

##  /0/pMod 10..17,INPUT|OUTPUT    

Set the Data Direction Register (DDRx) bit that sets a pin as INPUT or OUTPUT.

``` 
/1/pMod 10,OUTPUT
{"PB2":"OUTPUT"}
/1/pMod 14,INPUT
{"PC0":"INPUT"}
```

##  /0/dWrt 10..17,HIGH|LOW    

Set the Port Data Register (PORTx) bit that drives the pin or if mode (e.g. Port Input Register bit) is set as an INPUT enables a pullup. Returns the Port Input Register PINx bit (e.g. same as read command)

``` 
/1/dWrt 10,LOW
{"PB2":"LOW"}
/1/dWrt 14,HIGH
{"PC0":"LOW"}
```

Pin 14 is set as INPUT so it is not in the push-pull mode, the HIGH turns on a weak pullup and a LOW turns off the pullup. Since I have the SelfTest setup connected the ADC0 has 33.3 Ohm to ground and reads back a LOW.

##  /0/dTog 10..17

Toggle the Port Data Register (PORTx) bit if the Data Direction Register (DDRx) bit is set as an OUTPUT. Returns the Port Input Register PINx bit (e.g. same as read command)

``` 
/1/dTog 10
{"PC0":"HIGH"}
/1/dTog 10
{"PC0":"LOW"}
```

The board has a 127 Ohm output resistor that goes to the SelfTest wiring thus about 23mA is in the yellow LED when digital pin 10 is HIGH. 

##  /0/dRe? 10..17

Read the Port Input Register (PINx) bit that was latched during last low edge of the system clock.

``` 
/1/dRe? 14
{"PC0":"LOW"}
/1/dRe? 10
{"PB2":"LOW"}
```

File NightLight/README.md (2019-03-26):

# Night Light

## known bugs

If the sun is up after an MCU reset or power up then alternate power is not enabled until the next day. The workaround is to cover light sensor during reset or power up.

## Overview

RPUno has some current sources that can be used to light LED strings. CS0..CS3 are 22mA souces. Digital 13 is used for I2C status, and Digital 12 is used for Day-Night status. 

NightLight uses non-blocking timers to cycle through the led[1|2|3|4].cycle_state that is used to control the current sources. Each night the Night_AttachWork event runs. I have it disable the alternate power input and if the battery got charged load values from EEPROM to operate an LED non-blocking timer state machine. Each day the Day_AttachWork event runs. I have this enable the alternate power input and clear counters.

A 12V AGM LA battery is connected to the main power input. A solar panel is connected to the Alternate power input to allow charging the battery.  The Day_AttachWork() function is given a callback that is used to reset the accumulation values.

The solar panel short-circuit current needs to be less than about 1.5A so an SLP020-12U with Isc 1.3A should work, however an SLP030-12U with Isc 1.93 is too much. The battery should charge at 0.1C so for an SLP020-12U it needs to be at least 13AHr. If the charging is about 50% efficient then I will only get back about 3.25AHr of the 6.5AHr that was put in during a 5Hr charging time (that is about what I see). For a reasonable life expectancy, the battery should not discharge more than about 20%, so a minimum size that will do several hundred charge cycles is 16.25AHr.

# Wiring LED Strings to RPUno

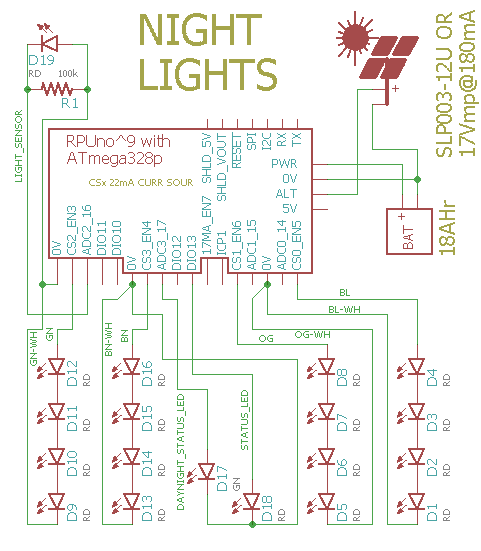
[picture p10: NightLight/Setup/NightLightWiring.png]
Wiring


The current sources drop a little over a diode voltage bellow the battery voltage, so the LED string needs to conduct at less than that (four red conduct at about 9V, five at 11.3V). 

# EEPROM Memory map 

A map of the LED timer settings in EEPROM. 

```
function            type    ee_addr:L1   L2   L3   L4
id                  UINT16          200  220  240  260
delay_start_sec     UINT32          202  222  242  262
runtime_sec         UINT32          206  226  246  266
delay_sec           UINT32          210  230  250  270
mahr_stop           UINT32          214  234  254  274
cycles              UINT16          218  238  258  278
```

This works like [Solenoid] except the mAHr_stop replaces flow_stop, it will stop the LED once that much current has been used from the battery. Also, the LED's do not have a resource constraint (i.e. the Flow Meter), so all the LED's can be used at once.

[Solenoid]: ../Solenoid

# Firmware Upload

With a serial port connection (see BOOTLOAD_PORT in Makefile) and optiboot installed on the RPUno run 'make bootload' and it should compile and then flash the MCU.

``` 
sudo apt-get install make git gcc-avr binutils-avr gdb-avr avr-libc avrdude
git clone https://github.com/epccs/RPUno/
cd /RPUno/NightLight
make bootload
...
avrdude done.  Thank you.
``` 

Now connect with picocom (or ilk). 

``` 
#exit is C-a, C-x
picocom -b 38400 /dev/ttyUSB0
``` 

# Commands

Commands are interactive over the serial interface at 38400 baud rate. The echo will start after the second character of a new line. 

## /\[rpu_address\]/\[command \[arg\]\]

rpu_address is taken from the I2C address 0x29 (e.g. ../Uart/id.h get_Rpu_address() ). The value of rpu_address is used as a character in a string, which means don't use a null value (C strings are null terminated), but the ASCII value for '1' (0x31) is easy and looks nice, though I fear it will cause some confusion when it is discovered that the actual address value is 49.

The STATUS_LED is bliked fast (twice per second) if the I2C address is not found, also the rpu_address defaults to '0'. 

Commands and their arguments follow.

## /0/id? \[name|desc|avr-gcc\]

Identify is from ../Uart/id.h Id().

``` 
/1/id?
{"err":"NotFinishLEDinit"}
/1/id?
{"id":{"name":"NightLight","desc":"RPUno (14140^9) Board /w atmega328p","avr-gcc":"5.4.0"}}
```

##  /0/runled led\[,cycles\] 

Start the led (1|2|3|4) operation, with option to override cycles (1..65635). 

If EEPROM settings have not been loaded the LED's retain the initialized values (delay_start = 1+(3*led), runtime = 1, delay = 3600, mahr_stop = MAHR_NOT_SET) that will cause each led to operate for a second after a delay_start time that spaces there operation out by 3 seconds each (it helps to test the setup).

```
/1/runled 1,5000
{"LED1":{"delay_start_sec":"1","runtime_sec":"1","delay_sec":"13","cycles":"5000"}}
/1/runled 2,5000
{"LED2":{"delay_start_sec":"4","runtime_sec":"1","delay_sec":"13","cycles":"5000"}}
/1/runled 3,5000
{"LED3":{"delay_start_sec":"7","runtime_sec":"1","delay_sec":"13","cycles":"5000"}}
/1/runled 4,5000
{"LED4":{"delay_start_sec":"10","runtime_sec":"1","delay_sec":"13","cycles":"5000"}}
```

##  /0/stopled led

Stop a running LED, reduce the delay_start, runtime, and delay to one second each to finish the led (1|2|3|4) operation without mixing up the state machine.

To change an led setting use /stop, then /load, and change the desired setting (e.g. /runtime) and finally save it and perhaps /run it.

```
/1/stopled 1
{"LED1":{"delay_start_sec":"1","runtime_sec":"1","delay_sec":"1","cycles":"1"}}
```

##  /0/preled led,delay_start_in_sec

Set the led (1|2|3|4) one time delay befor cycles run (1..21600, e.g. 6hr max). 

``` 
/1/preled 1,1
{"LED1":{"delay_start_sec":"1"}}
/1/preled 2,3
{"LED2":{"delay_start_sec":"3"}}
/1/preled 3,5
{"LED3":{"delay_start_sec":"5"}}
/1/preled 4,7
{"LED4":{"delay_start_sec":"7"}}
/1/runled 2,1
{"LED2":{"delay_start_sec":"3","runtime_sec":"1","delay_sec":"13","cycles":"1"}}
``` 

##  /0/runtimeled led,runtime_in_sec

Set the led (1|2|3|4) run time (1..21600, e.g. 6hr max). 

``` 
/1/runtimeled 1,4
{"LED1":{"runtime_sec":"4"}}
/1/runtimeled 2,5
{"LED2":{"runtime_sec":"5"}}
/1/runtimeled 3,4
{"LED3":{"runtime_sec":"4"}}
/1/runtimeled 4,5
{"LED4":{"runtime_sec":"5"}}
/1/runled 1,1
{"LED1":{"delay_start_sec":"1","runtime_sec":"4","delay_sec":"13","cycles":"1"}}
```

##  /0/delayled led,delay_in_sec

Set the led (1|2|3|4) delay between runs (1..86400, e.g. 24 hr max). 

```
/1/delayled 1,2
{"LED1":{"delay_sec":"2"}}
/1/delayled 2,2
{"LED2":{"delay_sec":"2"}}
/1/delayled 3,2
{"LED3":{"delay_sec":"2"}}
/1/delayled 4,2
{"LED4":{"delay_sec":"2"}}
/1/runled 3,1
{"LED3":{"delay_start_sec":"5","runtime_sec":"4","delay_sec":"2","cycles":"1"}}
```

##  /0/mahrled led,mAHr

Set the led (1|2|3|4) max discharge in mAHr (1..86400, e.g. 86.4AHr). When the battery has discharged by this amount the LED will stop.

```
/1/mahrled 1,400
{"LED1":{"mahr_stop":"400"}}
/1/mahrled 2,600
{"LED2":{"mahr_stop":"600"}}
/1/mahrled 3,800
{"LED3":{"mahr_stop":"800"}}
/1/mahrled 4,1000
{"LED4":{"mahr_stop":"1000"}}
/1/runled 3,1
{"LED3":{"delay_start_sec":"5","runtime_sec":"4","delay_sec":"2","cycles":"1","mahr_stop":"800"}}
```

##  /0/savled led,cycles 

Save the led (1|2|3|4) with cycles (1..65635) to EEPROM. A callback function is used to attach the callback_for_night_attach routine that loads these values at the start of the night (i.e. Night_AttachWork).

```
/1/saveled 1,5000
{"LED1":{"delay_start_sec":"1","runtime_sec":"4","delay_sec":"2","mahr_stop":"400","cycles":"5000"}}
/1/saveled 2,5000
{"LED2":{"delay_start_sec":"3","runtime_sec":"5","delay_sec":"2","mahr_stop":"600","cycles":"5000"}}
/1/saveled 3,5000
{"LED3":{"delay_start_sec":"5","runtime_sec":"4","delay_sec":"2","mahr_stop":"800","cycles":"5000"}}
/1/saveled 4,5000
{"LED4":{"delay_start_sec":"7","runtime_sec":"5","delay_sec":"2","mahr_stop":"1000","cycles":"5000"}}
```

##  /0/loadled led

Load the led (1|2|3|4) from EEPROM. Use run to start it.

```
/1/loadled 1
{"LED1":{"delay_start_sec":"1","runtime_sec":"4","delay_sec":"2","mahr_stop":"400","cycles":"5000"}}
/1/loadled 2
{"LED2":{"delay_start_sec":"3","runtime_sec":"5","delay_sec":"2","mahr_stop":"600","cycles":"5000"}}
/1/loadled 3
{"LED3":{"delay_start_sec":"5","runtime_sec":"4","delay_sec":"2","mahr_stop":"800","cycles":"5000"}}
/1/loadled 4
{"LED4":{"delay_start_sec":"7","runtime_sec":"5","delay_sec":"2","mahr_stop":"1000","cycles":"5000"}}
```

##  /0/led? led

Report the led (1|2|3|4) runtime in millis.

``` 
/1/led? 3
{"LED3":{"cycle_state":"0","cycles":"0","cycle_millis":"4000"}}
``` 

## [/0/analog? 0..7\[,0..7\[,0..7\[,0..7\[,0..7\]\]\]\]](../Adc#0analog-0707070707)

## [/0/iscan?](../i2c-debug#0iscan)

## [/0/iaddr 0..127](../i2c-debug#0iaddr-0127)

## [/0/ibuff 0..255\[,0..255\[,0..255\[,0..255\[,0..255\]\]\]\]](../i2c-debug#0ibuff-02550255025502550255)

## [/0/ibuff?](../i2c-debug#0ibuff)

## [/0/iwrite](../i2c-debug#0iwrite)

## [/0/iread?](../i2c-debug#0iread)

## [/0/charge?](../AmpHr#0charge)

## [/0/day?](../DayNight#0day)

## [/0/alt](../Alternat#0alt)

## [/0/altcnt?](../Alternat#0altcnt)

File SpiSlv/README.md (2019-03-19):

# AVR  Interrupt-Driven SPI slave

## Overview

SPI slave is an interactive command line program. CS0 is used to operate a status LED. nSS must be connected to Raspberry PI nCE00 pin (fixed on RPUpi^5).

## Pi SPI

After loading this RPUno firmware and enabling the AVR's SPI we can test the interface with the Raspberry Pi [SPI] hardware. Raspian needs its [SPI] master driver enabled (e.g. [raspi-config]).

[SPI]: https://www.raspberrypi.org/documentation/hardware/raspberrypi/spi/README.md
[raspi-config]: https://www.raspberrypi.org/documentation/configuration/raspi-config.md

Raspibin has an spi group setup in /etc/udev/rules.d/99-com.rules. I just need to add my user name to the group for the system to allow me to use the device.

``` 
sudo usermod -a -G spi rsutherland
# logout for the change to take
``` 

Compile spidev_test.c on the Pi with:

``` 
wget https://raw.githubusercontent.com/raspberrypi/linux/rpi-3.10.y/Documentation/spi/spidev_test.c
gcc -o spidev_test spidev_test.c
# run with
./spidev_test -s 100000 -D /dev/spidev0.0
./spidev_test -s 500000 -D /dev/spidev0.0
./spidev_test -s 1000000 -D /dev/spidev0.0
./spidev_test -s 2000000 -D /dev/spidev0.0
./spidev_test -s 500000 -D /dev/spidev0.0
./spidev_test -s 500000 -D /dev/spidev0.0

spi mode: 0
bits per word: 8
max speed: 500000 Hz (500 KHz)

0D FF FF FF FF FF
FF 40 00 00 00 00
95 FF FF FF FF FF
FF FF FF FF FF FF
FF FF FF FF FF FF
FF DE AD BE EF BA
AD F0
``` 

Note: The output is offset a byte since it was sent back from the AVR. 

## Wiring Setup

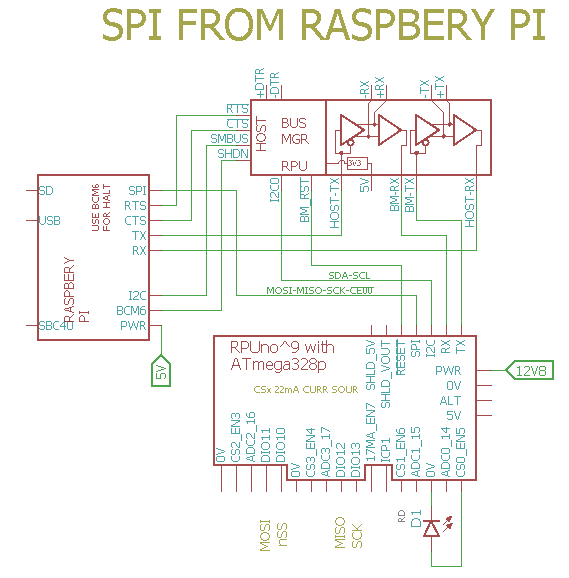
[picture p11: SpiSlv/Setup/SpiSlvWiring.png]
Wiring


## Firmware Upload

If the host computer is a Raspberry Pi the rpubus manager needs set so that it can bootload. Connect with picocom (or ilk).

``` 
picocom -b 38400 /dev/ttyAMA0
/1/iaddr 41
{"address":"0x29"}
#set a rpubus bootload address
/1/ibuff 3,49
{"txBuffer[2]":[{"data":"0x3"},{"data":"0x31"}]}
/1/iread? 2
{"rxBuffer":[{"data":"0x3"},{"data":"0x31"}]}
#clear the bus manager status bits so the host can bootload
/1/ibuff 7,0
{"txBuffer[2]":[{"data":"0x7"},{"data":"0x0"}]}
/1/iread? 2
#exit is C-a, C-x
``` 

With a serial port connection and optiboot installed on the RPUno run 'make bootload' and it should compile and then flash the MCU.

``` 
sudo apt-get install make git gcc-avr binutils-avr gdb-avr avr-libc avrdude
git clone https://github.com/epccs/RPUno/
cd /RPUno/SpiSlv
make bootload
...
avrdude done.  Thank you.
``` 

# Commands

Commands are interactive over the serial interface at 38400 baud rate. The echo will start after the second character of a new line. 

## /\[rpu_address\]/\[command \[arg\]\]

rpu_address is taken from the I2C address 0x29 (e.g. get_Rpu_address() which is included form ../lib/rpu_mgr.h). The value of rpu_address is used as a character in a string, which means don't use a null value (C strings are null terminated) as an adddress. The ASCII value for '1' (0x31) is easy and looks nice, though I fear it will cause some confusion when it is discovered that the actual address value is 49.

## /0/id? \[name|desc|avr-gcc\]

identify 

``` 
/1/id?
{"id":{"name":"SpiSlv","desc":"RPUno (14140^7) Board /w atmega328p","avr-gcc":"4.8"}}
``` 

## /0/spi UP|DOWN

Turn on SPI. This enables SPI slave mode which exchanges data in shift registers. An UP will pull down DIO3 and enable the SPI hardware, DIO3 can be connected to nSS (a.k.a. DIO10) so that it activates the SPI slave hardware (nSS can also be connected to 0V). 

``` 
/1/spi UP
{"SPI":"UP"}
```

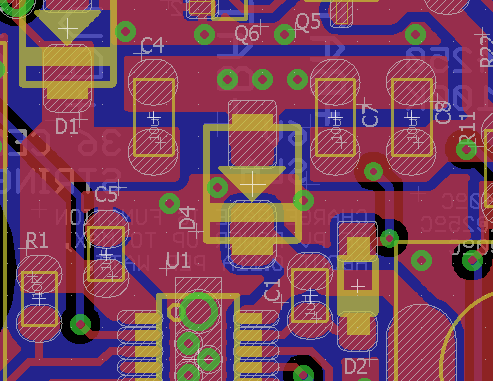
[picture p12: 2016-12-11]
Hardware/Schooling/14140^3,WithSwitchingIsland.png

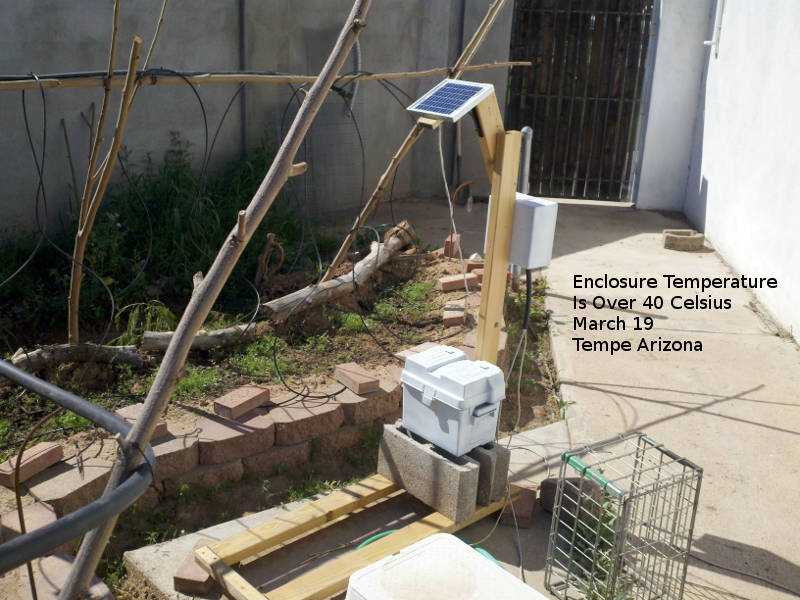
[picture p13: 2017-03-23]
Hardware/Schooling/14140^5,Enclosure.jpg

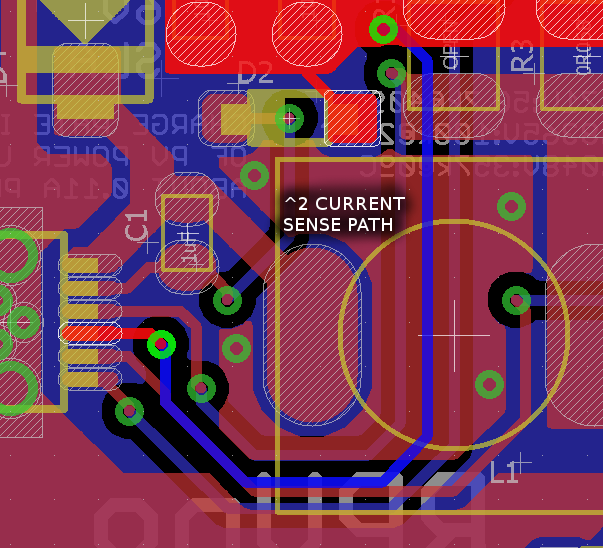
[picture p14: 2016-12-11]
Hardware/Schooling/14140^2,CurrentSensePath.png

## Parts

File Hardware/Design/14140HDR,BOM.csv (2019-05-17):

LINE | REF | QTY | EPCCS TYP | EPCCS PN | MFG@PN | DESCRIPTION | NOTES | COST EA | LINE COST | BIN
 |  |  |  |  |  | RPUno Headers |  |  | TOTAL
 |  |  |  |  |  | 9/2/18 (14140^9) |  |  | =SUM(J5:J100)
1 | D2 | 1 | D-LED | 5MMGN | CREE@C503B-GCN-CY0C0791 | LED GREEN 5MM 3.2V@20MA | (1) | 0.21 | =C5*I5 | ONESHOT
2 | J5 J9 J10 | 3 | J-HDR2.54mm | PPPC101LFBN | SULLINS@PPPC101LFBN-RC | CONN HEADER FEMALE .1IN 10POS | (1) | 0.518 | =C6*I6 | IRRIGATE7
3 | J6 | 1 | J-HDR2.54mm | PPPC081LFBN | SULLINS@PPPC081LFBN-RC | CONN HEADER FEMALE .1IN 8POS | (1) | 0.518 | =C7*I7 | IRRIGATE7
4 | J11 | =1*3/36 | J-HDR2.54mm | PBC36DAAN | SULLINS@PBC36DAAN | HEADER MALE BRKWAY .1IN AA 36X2POS 1 SET 3X2 | (1 4) | 3.77 | =C8*I8 | IRRIGATE7
5 | J12 | =0*6/36 | J-HDR2.54mm | PBC36SAAN | SULLINS@PBC36SAAN | HEADER MALE BRKWAY .1IN AA 36POS 1 SET OF 6 | (1) | 1.882 | =C7*I7 | SHLD
6 | J13 | 0 | J-HDR2mm | S4B | JST@S4B-PH-K-S | CONN HEADER SIDE THRU 4POS | (1) | 0.208 | =C10*I10 | IRRIGATE7
7 | U2 | 1 | U-DCDC | I50115 | MURATA PS@OKI-78SR-5 | SMPS 5V 1500MA SIP3 | (1) | 4.228 | =C11*I11 | RPUNO
 |  |  |  |  |  | NOTES
 |  |  |  |  |  | (1) Alternate part with same or better rating allowed
 |  |  |  |  |  | (4) Cut 36 pin to needed size

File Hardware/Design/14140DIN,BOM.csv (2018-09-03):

LINE | REF | QTY | EPCCS TYP | EPCCS PN | MFG@PN | DESCRIPTION | NOTES | COST EA | LINE COST | BIN
 |  |  |  |  |  | RPUno DIN |  |  | TOTAL
 |  |  |  |  |  | 9/2/18 (14140^9) |  |  | =SUM(J5:J100)
1 | HW1 HW2 | 2 | HW-DINMNT | USA10-4.6 | PHXCONT@1201578 | DINRAIL ADAPTER UNIVERSAL 10MM 2.75MM | (1) | 1.13 | =C5*I5 | SHLD
2 |  | 4 | HW-SCREW | ZN6PSMS38 | B&F@PSMS 006 0038 PH | PAN SHT MTL SCREW #6 PHP .38L ZN | (1) | 0.1022 | =C6*I6 | SHLD
 |  |  |  |  |  | NOTES
 |  |  |  |  |  | (1) Alternate part with same or better rating allowed

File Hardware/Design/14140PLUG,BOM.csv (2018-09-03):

LINE | REF | QTY | EPCCS TYP | EPCCS PN | MFG@PN | DESCRIPTION | NOTES | COST EA | LINE COST | BIN
 |  |  |  |  |  | RPUno Plugs |  |  | TOTAL
 |  |  |  |  |  | 9/2/18 (14140^9) |  |  | =SUM(J5:J100)
1 | J1 J2 J4 | =3*5/16 | J-HDR3.5mm | PST1.0&16-3.5 | PHOENIX_CONTACT@1945232 | CONN HEADER STRIP PIN 3.5MM 16POS 3 SET OF 5 | (6 2) | 1.13 | =C5*I5 | SHLD
2 | J3 | =1*2/16 | J-HDR3.5mm | PST1.0&16-3.5 | PHOENIX CONTACT@1945232 | CONN HEADER STRIP PIN 3.5MM 16POS 2 SET OF 2 | (6 2) | 1.13 | =C6*I6 | SHLD
3 | J4 | =1*4/16 | J-HDR3.5mm | PST1.0&16-3.5 | PHOENIX CONTACT@1945232 | CONN HEADER STRIP PIN 3.5MM 16POS 1 SET OF 4 | (6 2) | 1.13 | =C7*I7 | SHLD
4 |  | 1 | J-HDR3.5mm | PT1.5/2-PVH-3.5 | PHOENIX CONTACT@1984015 | CONN PLUG STRIP 3.5MM 1 SET OF 2POS | (2) | 0.42 | =C8*I8 | SHLD
5 |  | 1 | J-HDR3.5mm | PT1.5/4-PVH-3.5 | PHOENIX CONTACT@1984015+1984015 | CONN PLUG STRIP 3.5MM 1 SET OF 2+2POS | (2 6) | 0.43+0.43 | =C9*I9 | SHLD
6 |  | 3 | J-HDR3.5mm | PT1.5/5-PVH-3.5 | PHOENIX CONTACT@1984015+1984028 | CONN PLUG STRIP 3.5MM 3 SET OF 2+3POS | (2) | =0.43+0.60 | =C10*I10 | SHLD
 |  |  |  |  |  | NOTES
 |  |  |  |  |  | (1) Alternate part with same or better rating allowed
 |  |  |  |  |  | (2) for x in (2 4 6 8): PST 1.0/x-3.5 mates with PT 1.5/x-PVH-3.5
 |  |  |  |  |  | (4) Cut 36 pin to needed size
 |  |  |  |  |  | (6) Cut 16 pin to needed size

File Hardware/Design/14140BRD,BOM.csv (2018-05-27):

LINE | REF | QTY | EPCCS TYP | EPCCS PN | MFG@PN | DESCRIPTION | NOTES | COST EA | LINE COST | BIN
 |  |  |  |  |  | RPUno Board |  |  | TOTAL
 |  |  |  |  |  | 1/30/18 (14140^9) |  |  | =SUM(J5:J100)
1 |  | =1/3 | BOARD | OSHPARK |  | PCB 2 LAYER ENIG 3 COPY | () | 35.75 | =C5*I5 | RPUNO
 |  |  |  |  |  | NOTES

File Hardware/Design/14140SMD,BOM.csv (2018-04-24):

LINE | REF | QTY | EPCCS TYP | EPCCS PN | MFG@PN | DESCRIPTION | NOTES | COST EA | LINE COST | BIN
 |  |  |  |  |  | RPUno SMD |  |  | TOTAL
 |  |  |  |  |  | 1/24/18 (14140^9) |  |  | =SUM(J5:J100)
1 | C1 | 1 | C-C | 1206X5R50V106K | TDK@C3216X5R1H106K160AB | CAP CER 10UF 50V 10% X5R 1206 | (1) | .3575 | =C5*I5 | CC01
2 | C2 C4 C7 C12 C13 C14 C17 | 7 | C-C | 0603X7R50V104K | TDK@C1608X7R1H104K080AA | CAP CER 0.1UF 50V 10% X7R 0603 | (1) | 0.0055 | =C6*I6 | ADPT
3 | C3 C8 C9 C10 C11 | 5 | C-C | 0603X7R50V103K | MURATA@GRM188R71H103KA01J | CAP CER 10000PF 50V 10% X7R 0603 | (1) | 0.007 | =C7*I7 | HT
4 | C5 | 1 | C-C | 0805X7R50V105K | TAIYO@UMK212B7105KG-T | CAP CER 1UF 50V 10% X7R 0805 | (1) | 0.136 | =C8*I8 | CC01
5 | C6 | 1 | C-T | 106A | AVX@TPSA106K010R0900 | CAP TANT 10UF 10V 10% ESR .9OHM 1206 | (1) | 0.3575 | =C9*I9 | ADPT
6 | C15 C16 | 2 | C-C | 0603NPO50V270J | SAMSUNG@CL10C270JB8NNNC | CAP CER 27PF 50V 5% NPO 0603 | (1) | 0.0067 | =C10*I10 | RPUNO
7 | D1 | 1 | D-SBR | SQ4 | DIODES@SBR2A40SA | DIODE SBR 40V 2A SMA | (1) | 0.289 | =C11*I11 | CC01
8 | D3 | 1 | D-GP | T4 | DIODES@1N4148W-7-F | DIODE SWITCH 100V 0.15A SOD123 | (1) | 0.0601 | =C12*I12 | CC01
9 | L1 | 0 | L-FB | MH2029-300Y | BORNS@MH2029-300Y | FERRITE SMDBEAD 30OHM@100MHZ 3A 0805 | (1) | 0.0272 | =C13*I13 | ADPT
10 | Q1 Q6 Q10 Q12 Q16 Q17 Q18 Q22 Q23 Q27 Q28 Q32 Q34 Q38 Q40 Q41 | 16 | Q-NPN | K1N | DIODES@MMBT3904-7-F | TRANSISTOR NPN GP 40V 200MA SOT23 | (1) | 0.0204 | =C14*I14 | IRRIGATE7
11 | Q2 Q4 Q8 | 3 | Q-PCH | P65 | DIODES@DMP4065S-7 | MOSFET P-CH 2.4A 40V SOT23 | (1) | 0.2196 | =C15*I15 | PUNICA
12 | Q3 Q9 Q11 Q13 Q20 Q21 Q25 Q26 Q30 Q31 | 10 | Q-NCH | K38 | DIODES@BSS138-7-F | MOSFET N-CH 200MA 50V SOT23 | (1) | 0.1132 | =C16*I16 | ADPT
13 | Q5 Q7 Q14 Q15 Q19 Q24 Q29 Q33 Q35 Q36 Q37 Q39 | 12 | Q-PNP | K3N | DIODES@MMBT3906-7-F | TRANSISTOR PNP GP 40V 200MA SOT23 | (1) | 0.0204 | =C17*I17 | HT
14 | R1 R9 R14 R16 | 4 | R-C | 0805KX1003 | YAGEO@RC0805FR-07100KL | RESISTOR CHIP 1% 100KOHM 0805 | (1) | 0.0025 | =C18*I18 | IRRIGATE7
15 | R2 R19 R30 R32 R35 R39 | 6 | R-C | 0805KX4992 | YAGEO@RC0805FR-0749K9L | RESISTOR CHIP 1% 49K9OHM 0805 | (1) | 0.0025 | =C19*I19 | IRRIGATE7
16 | R3 R8 R10 R20 R31 R33 R36 R37 R40 R42 R43 | 11 | R-C | 0805KX1002 | YAGEO@RC0805FR-0710KL | RESISTOR CHIP 1% 10KOHM 0805 | (1) | 0.0025 | =C20*I20 | ADPT
17 | R4 | 1 | R-C | 0805KX1001 | YAGEO@RC0805FR-071KL | RESISTOR CHIP 1% 1KOHM 0805 | (1) | 0.0025 | =C21*I21 | HT
18 | R5 | 1 | R-C | 0805FX1003 | YAGEO@RT0805BRD07100KL | RESISTOR CHIP 0.1% 100KOHM 0805 | (1) | 0.1277 | =C22*I22 | LUX
19 | R6 | 1 | R-C | 0805KX1582 | YAGEO@RC0805FR-0715K8L | RESISTOR CHIP 1% 15K8OHM 0805 | (1) | 0.0064 | =C23*I23 | IRRIGATE7
20 | R7 | 1 | R-C | 0805KX0R068 | SAMSUNG@RU2012FR068CS | RESISTOR CHIP 1% 0R068OHM 0805 | (7) | 0.0899 | =C24*I24 | CC03
21 | R11 | 0 |  | JMP |  |  |  | 0.0 | =C25*I25 | NA
22 | R12 | 0 |  | OPEN |  |  |  | 0.0 | =C26*I26 | NA
23 | R13 | 1 | R-C | 0805KX8062 | YAGEO@RC0805FR-0780K6L | RESISTOR CHIP 1% 80K6OHM 0805 | (1) | 0.0025 | =C27*I27 | CC01
24 | R15 R17 R22 R23 R25 R26 R28 R29 | 8 | R-C | 0805KX127R | YAGEO@RC0805FR-07127RL | RESISTOR CHIP 1% 127OHM 0805 | (1) | 0.0024 | =C28*I28 | PUNICA
25 | R18 R21 R24 R27 | 4 | R-C | 0805KX27R0 | YAGEO@RC0805FR-0727R0L | RESISTOR CHIP 1% 27R0OHM 0805 | (1) | 0.0064 | =C29*I29 | FTDI
26 | R34 | 1 | R-C | 0805KX32R4 | YAGEO@RC0805FR-0732R4L | RESISTOR CHIP 1% 32R4OHM 0805 | (1) | 0.0064 | =C30*I30 | RPUNO
27 | R38 | 1 | R-C | 0805KX100R | YAGEO@RC0805FR-07100RL | RESISTOR CHIP 1% 100OHM 0805 | (1) | 0.0024 | =C31*I31 | ADPT
28 | R41 | 1 | R-C | 0805KX182R | YAGEO@RC0805FR-07182RL | RESISTOR CHIP 1% 182OHM 0805 | (1) | 0.0025 | =C32*I32 | IRRIGATE7
29 | U1 | 1 | U-LINEAR | 1087 | DIODES@ZXCT1087E5TA | HISIDE CURRENT MONITOR SOT23-5 | (1) | 1.0661 | =C33*I33 | CCTEST
30 | U3 | 1 | U-AVR | MEGA328P | ATMEL@ATMEGA328P-AU | MCU AVR8 32KB FLASH 20MHZ 32TQFP | () | 1.8952 | =C34*I34 | RPUNO
31 | Y1 | 1 | Y-XTL | 16MHZ20 | ECS@ECS-160-20-3X-TR | CRYSTAL 16MHZ 20PF 30PPM CSM-3X | (1) | 0.315 | =C35*I35 | RPUNO
 |  |  |  |  |  | NOTES
 |  |  |  |  |  | (1) Alternate part with same or better rating allowed

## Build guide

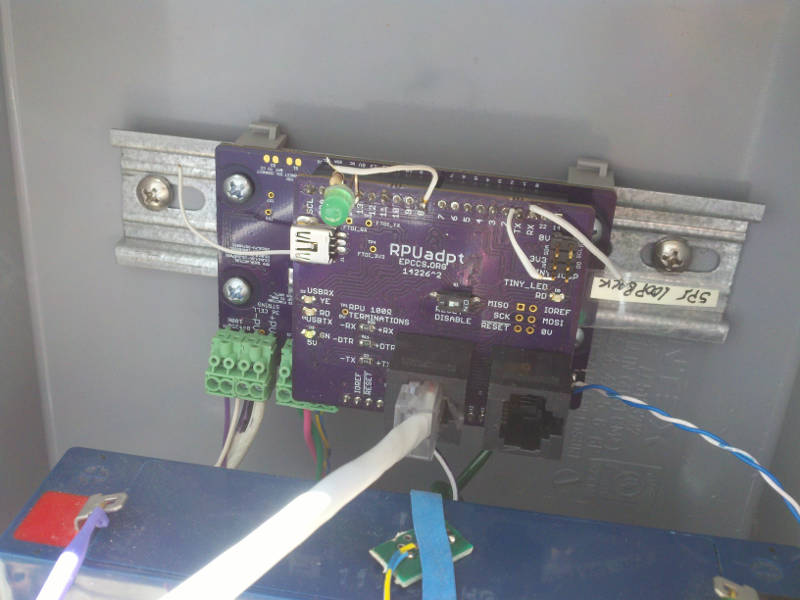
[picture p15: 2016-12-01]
Hardware/Evaluation/14140^2_ADC60SecIntervalSetupBox.jpg

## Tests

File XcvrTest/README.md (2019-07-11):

# Transceiver Test

## Overview

Check Transceivers on an RPUpi, this runs once after a reset and then loops in a pass/fail section.

Test commands are issued to the manager's I2C port to operate it in test_mode. The manager needs to be loaded with its firmware (e.g., RPUpi's [Remote] firmware) 

[Remote]: https://github.com/epccs/RPUpi/tree/master/Remote

The wiring (from SelfTest) has a red and green LED that blink to indicate test status.

## Wiring Needed for Transceiver Test

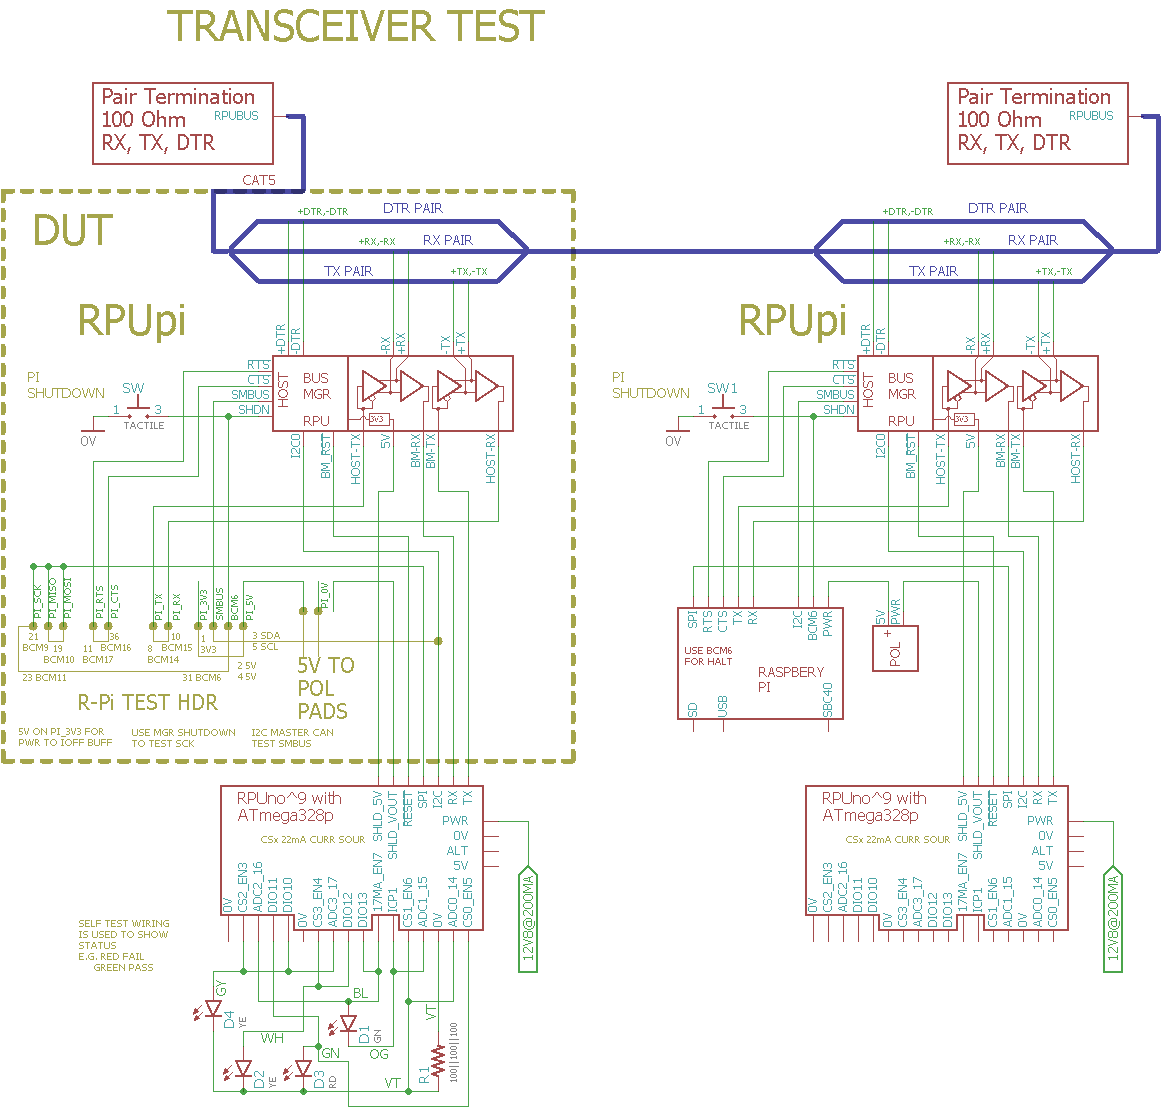
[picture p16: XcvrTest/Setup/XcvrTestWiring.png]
Wiring


## Power Supply

Connect a power supply with CV and CC mode. Set CC at 200mA and CV at 12.8V.

## Firmware Upload

The wiring shows two RPUpi (one is the DUT) and two RPUno. An R-Pi Zero is used as a host on the know good RPUno and its RPUpi. [Remote] has been loaded on the known good and DUT RPUpi's.

[Remote]: https://github.com/epccs/RPUpi/tree/master/Remote

The known good RPUno has been loaded with [i2c-debug]. 

[i2c-debug]: https://github.com/epccs/RPUno/tree/master/i2c-debug

Connect the bootload port of the RPUno that will be under the DUT with [USBuart] or [ICSP] and load this test firmware on it, run 'make' to build and then 'make bootload' to flash it. 

[ICSP]: https://github.com/epccs/Driver/tree/master/ICSP
[USBuart]: https://github.com/epccs/Driver/tree/master/USBuart

``` 
git clone https://github.com/epccs/RPUno/
cd /RPUno/XcvrTest
make
make bootload
...
avrdude done.  Thank you.
make clean
``` 

Now power down the RPUno with the loaded test firmware and plug in the DUT. When the power is applied the test will run and we can see the resutls on the Bootload port with [USBuart] and picocom (exit is C-a, C-x). 

``` 
picocom -b 38400 /dev/ttyUSB0
picocom v2.2
...
Terminal ready
RPUpi Transceiver Test date: Jul 11 2019
avr-gcc --version: 5.4.0
I2C provided address 0x31 from manager
SMBUS cmd 0 provided address 49 from manager
MISO loopback to MOSI == HIGH
MISO loopback to MOSI == LOW
SCK with Shutdown loopback == HIGH
I2C Shutdown cmd is clean {5, 1}
SCK with Shutdown loopback == LOW
I2C Shutdown Detect cmd is clean {4, 1}

Testmode: default trancever control bits
I2C Start Test Mode cmd was clean {48, 1}
I2C End Test Mode hex is Xcvr cntl bits {49, 0xD5}
Testmode: read  Xcvr cntl bits {50, 0xE2}
PWR_I /w no load using INTERNAL_1V1: 0.024 A

Testmode: nCTS loopback to nRTS
I2C Start Test Mode cmd was clean {48, 1}
I2C End Test Mode hex is Xcvr cntl bits {49, 0xD5}
Testmode: set  Xcvr cntl bits {51, 0xA2}
Testmode: read  Xcvr cntl bits {50, 0x22}

Testmode: Enable TX pair driver
I2C Start Test Mode cmd was clean {48, 1}
I2C End Test Mode hex is Xcvr cntl bits {49, 0xD5}
Testmode: set  Xcvr cntl bits {51, 0xF2}
Testmode: read  Xcvr cntl bits {50, 0xF2}
PWR_I /w TX pair load: 0.044 A

Testmode: Enable TX & RX(loopback) pair drivers
I2C Start Test Mode cmd was clean {48, 1}
I2C End Test Mode hex is Xcvr cntl bits {49, 0xD5}
Testmode: set  Xcvr cntl bits {51, 0xD1}
Testmode: read  Xcvr cntl bits {50, 0xD1}
PWR_I /w TX and RX pairs loaded: 0.066 A
RX loopback checked

Testmode: Enable DTR pair driver
I2C Start Test Mode cmd was clean {48, 1}
I2C End Test Mode hex is Xcvr cntl bits {49, 0xD5}
Testmode: set  Xcvr cntl bits {51, 0xE6}
Testmode: read  Xcvr cntl bits {50, 0xE6}
PWR_I /w DTR pair load: 0.044 A
[PASS]
```

The resutls can also be seen on the remote R-Pi host, but if something goes wrong the bootload port may be needed to see the test results.

The test is not done, I will start working on it soon.

It needs to place the manager in test mode and measure quit a few things and then exit test mode and write the results to serial. 

I was a test engineer for many years, I use to think about testing from the outside into the inside, but this is from the inside to the outside. If the test fails the bootload port will be needed, I fear that during the analysis the host UART connected to the bootload port will be trashed with garbage, but I think clean data can be sent after the trash.

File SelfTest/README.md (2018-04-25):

# Self-Test

## Overview

Check RPUno Board Functions, runs once after a reset and then loops in a pass/fail section.

ICP1 (PL) has a 100 Ohm resistor to 0V on board.

Voltage references are saved in EEPROM for use with Adc and other applications. Measure the +5V supply accurately and set the REF_EXTERN_AVCC value in the main.c file. The band-gap reference is calculated and also saved.

The wiring has red and green LED that blink to indicate test status.

## Wiring Needed for RPUno

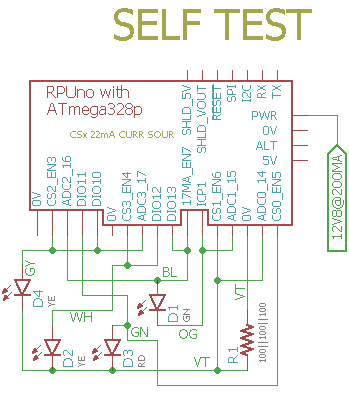
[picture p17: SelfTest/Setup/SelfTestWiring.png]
Wiring


Note: blocking diode with LED is to prevent damage when connected wrong.

## Power Supply

Connect a power supply with CV and CC mode. Set CC at 150mA then increase CV to 12.8V.

## Firmware Upload

With a serial port setup for serial bootloading (see BOOT_PORT in Makefile) and optiboot installed on the RPUno run 'make bootload' and it should build the code and then flash the MCU.

``` 
git clone https://github.com/epccs/RPUno/
cd /RPUno/SelfTest
make bootload
...
avrdude done.  Thank you.
make clean
``` 

Now connect with picocom (exit is C-a, C-x). 

``` 
picocom -b 38400 /dev/ttyUSB0
picocom v2.2
...
Terminal ready
RPUno Self Test date: Apr 23 2018
avr-gcc --version: 5.4.0
I2C provided address 0x31 from RPUadpt serial bus manager
adc reading for PWR_V: 355
PWR at: 12.722 V
ADC0 R1 /W all CS off: 0.000 V
ADC1 at ICP1 TERM /w all CS off: 0.000 V
ADC2 at GN LED /w DIO13 sinking and all CS off: 0.000 V
ADC3 at YE LED /w DIO10 sinking and all CS off: 0.000 V
ICP1 input should be HIGH with 0mA loop current: 1 
CS0 on R1: 0.022 A
DIO11 shunting CS0: 0.014 A
CS1 source on R1: 0.022 A
   ADC0 reading used to calculate ref_intern_1v1_uV: 689 A
   calculated ref_intern_1v1_uV: 1082791 uV
REF_EXTERN_AVCC old value found in eeprom: 5007000 uV
REF_INTERN_1V1 old value found in eeprom: 1082204 uV
REF_EXTERN_AVCC from eeprom is same
PWR_I at no load use INTERNAL_1V1: 0.012 A
CS2 source on R1: 0.022 A
Yellow LED D4 fwd /w CS2 V: 2.112 V
DIO10 shunting CS2: 0.015 A
CS3 source on R1: 0.022 A
DIO12 shunting CS3: 0.015 A
CS_ICP1 in UUT PL input: 0.018 A
Green LED D1 fwd /w CS_ICP1 V: 2.147 V
ICP1 /w 17mA on termination reads: 0 
DIO13 shunting CS_ICP1: 0.015 A
[PASS]
```

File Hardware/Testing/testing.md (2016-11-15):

# Description

This is a list of Test preformed on each RPUno after assembly.

# Table of References

# Table Of Contents:

    1. Basics
    2. Assembly check
    3. IC Solder Test
    4. Reverse Battery Protection
    5. Battery Disconnect
    6. Power Protection
    7. TPS3700 Window Comparator
    8. LT3652 Power Up Without Battery
    9. LT3652 Load Test
    10. +5V From OKI-78SR-5
    11. 20mA Source
    12. Set MCU Fuse and Install Bootloader

## Basics

These tests are for an assembled RPUno board 14140^5 which may be referred to as a Unit Under Test (UUT). If the UUT fails and can be reworked then do so, otherwise it needs to be scraped. 

**Warning: never use a soldering iron to rework ceramic capacitors due to the thermal shock.**
    
Items used for test.

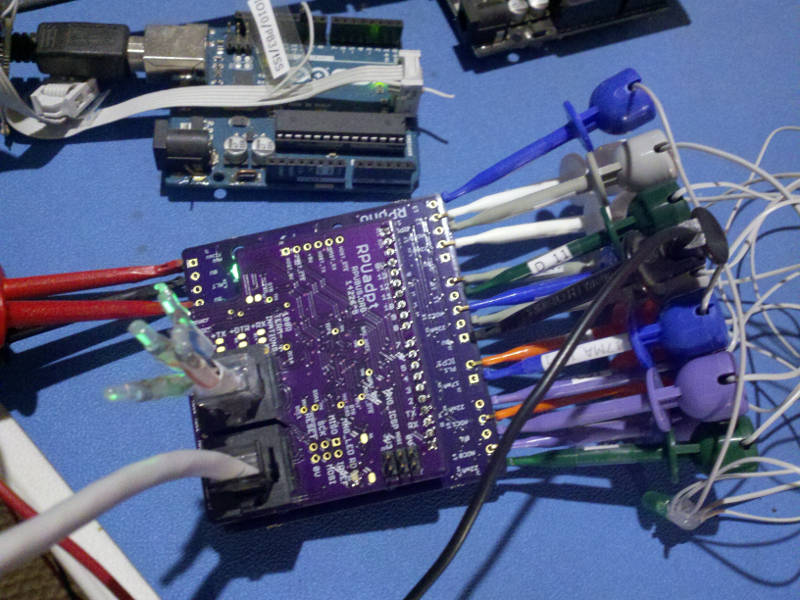
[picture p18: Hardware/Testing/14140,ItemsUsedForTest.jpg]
ItemsUsedForTest RPUno Items Used For Test


## Assembly check

After assembly check the circuit carefully to make sure all parts are soldered and correct, note that the device making is labeled on the schematic and assembly drawing.
    
NOTE: U2 is not yet on the board, so everything with +5V will not have power.

## IC Solder Test

The bottom pad on U1 dissipates heat as well as providing a ground, it is not connected to any other pin. The 0V plane is ground for this test. Check that a diode drop is present from each pin to the ground by measuring with a DMM's diode test between each pin and the 0V plane (reversed polarity). U1 pins 12, 10 and 9 are connected to L1 and R3 and read with a low (.13V) value. U2 not pop yet. U3 and U4 give a diode value on pins 1 and 5, while pins 3 and 4 are connected to R3 and L1 and read with a low value. U5 and U6 gives normal diode values where expected. U5 pin 2 and U6 pins 3, 5, 21 are connectd to ground and should have a short to 0V.

## Reverse Battery Protection

Apply a current limited (&lt;20mA) supply set with 14V to the +BAT and -BAT connector in reverse and verify that the voltage does not get through to TP4 (^4 PWR). Note some voltage (.2V) will be seen on TP4 because of how the shutdown through Q3 works.

## Battery Disconnect

Apply a current limited (&lt;20mA) supply set with 14V to the +BAT and -BAT connector and verify that voltage does not get through to TP4. 

## Power Protection

Apply a current limited (20mA) supply to the PV input with reverse polarity and ramp the voltage up to 30V, verify that no current flows.

## TPS3700 Window Comparator 

Connect a 20mA rated LED between J4.1 and J4.3. Apply a current limited (&lt;50mA) supply starting at 12V to the +BAT and -BAT connector. Short S2 and then release it, which will force the battery to connect. Check that TP4 has been latched e.g. has voltage from supply. Increase the supply slowly until the LED turns on, but no more than 14V. This is the voltage at which the load connects, and should be about 13.1V. Now slowly reduce the supply until the LED turns off. This is the voltage at which the battery disconnects and should be about 11.58V. The parts used determine the actual voltages. 

```
        TODO:  some data from unit(s)
            { "LOAD_CONNNECT":[12.95,12.99,],
               "DISCONNECT":[11.42,11.45,] }
```

## LT3652 Power Up Without Battery

Connect 100 kOhm resistor to both the PV side and BAT side thermistor inputs to simulate room temperature. Connect an LED with 1k Ohm series resistor to the +LD and -LD. Apply a current limited (50mA) supply to the +PV and -PV inputs and adjust it to about 14V. Verify no output.  Next adjust the supply to 19V and verify a regulated voltage (13.63V) between +BAT and -BAT* pins. 

NOTE: the LT3652 goes into fault when started into my HP6050A in CC mode, which is by design. I can start the LT3652 with the load off, or in CV mode and then switch to CC. This note is to remind me that it is an expected behavior.

```
        TODO:  some data from unit(s)
            { "VOUT100K":[13.55,13.65,] }
```

## LT3652 Load Test

NOTE: this test is likely beyond the scope of the DIY, but anyone making more than a few of these should load test the converter and make sure it can dissipate heat.

Connect 100 kOhm resistor to both the PV side and BAT side thermistor inputs to simulate room temperature. Connect a 20mA rated LED between J4.1 and J4.3. A voltage mode electronic load is used for this test, however, a partly discharged battery may also give results. Connect the electronic load between  the +BAT and -BAT pins. Set the electronic load voltage to 12.8V to simulate a battery. Connect +PV and -PV to a CC/CV mode supply with CC set at 150mA and CV set at 21V, apply the power. Verify the solar power point voltage is about 16.9V with the supply current CC at 150mA. Increase the supply CC setting until its voltage increases to 21V, e.g. the supply changes from CC to CV mode, and check that the charge controller is current limiting at about 1A with 0R068 placed on R3, also check if U1 (LT3652) is getting hot. Note that the voltage at UUT is higher than at the load because the wires drop some voltage (the load is still running at the 12.8V). 

```
        TODO:  some data from unit(s)
            { "PP100K@150mA&amp;12V8":[16.86,16.88],
               "CURR_LIMIT":[1.28,1.30,] }
```

## +5V From OKI-78SR-5

NOTE: U2 needs added to the board.

Power up like durring the load test and check the +5V supply at the ICSP header (e.g. between IOREF and 0V)

```
        TODO:  some data from unit(s)
            { "+5V":[5.00,4.99] }
```

## Current Sources

Use a DMM to measure the 22mA current source for A0 from J4.1 to J4.3 (V0) and A1 from J4.5 to J4.3. Pulse Loop 17mA source, and Pulse Pull 10mA pull up current source. Digital IO 22mA current source. 
    
NOTE: 17MA_PL and 10MA_PL need IO9 pulled up to IOREF (the pin is floating).

```
        TODO:  some data from unit(s)
            { "22MA_A0":[20.7,21.6,],
               "22MA_A1":[21.1,21.8,],
               "17MA_PL":[18.6,18.4,],
               "10MA_PL":[10.2,10.0,],
               "22MA_IO":[21.7,22.0,]}
```

## Set MCU Fuse and Install Bootloader

The MCU needs its fuses set, so a Makefile is used to do that. Apply a 5V current limited source (about 30mA*) to +5V. Check that the input current is for a blank MCU (e.g. less than 5mA).

Use the <https://github.com/epccs/RPUadpt/tree/master/Bootload> Makefile 

Connect the ICSP tool and run "make fuse" to program the fuses, next run "make isp" to install the bootloader.Disconnect the ICSP tool and measure the input current. Turn off power.

```
        TODO:  some data from unit(s)
            { "I_IN_BLANKMCU_mA":[4.2,],
            "I_IN_16MHZ_EXT_CRYST_mA":[11.0,]}
```

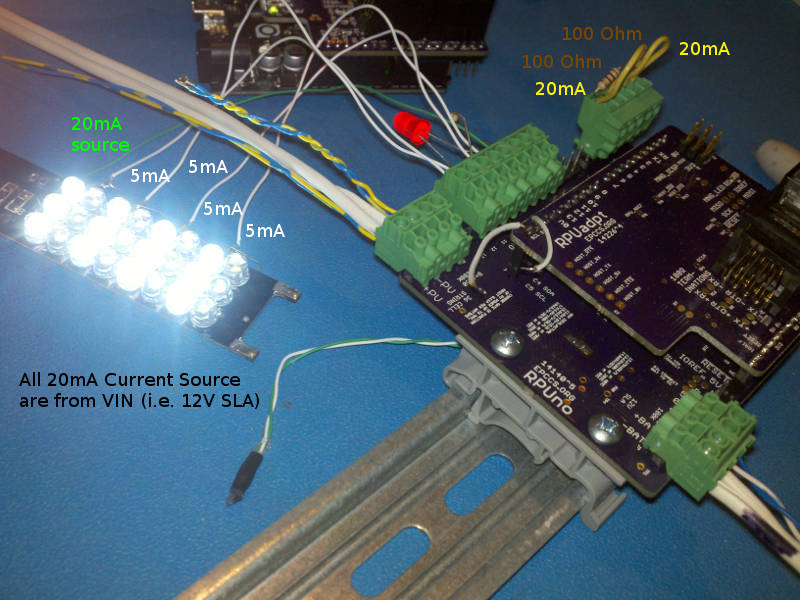
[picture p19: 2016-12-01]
Hardware/Evaluation/RPUno^5_DioAdc.jpg

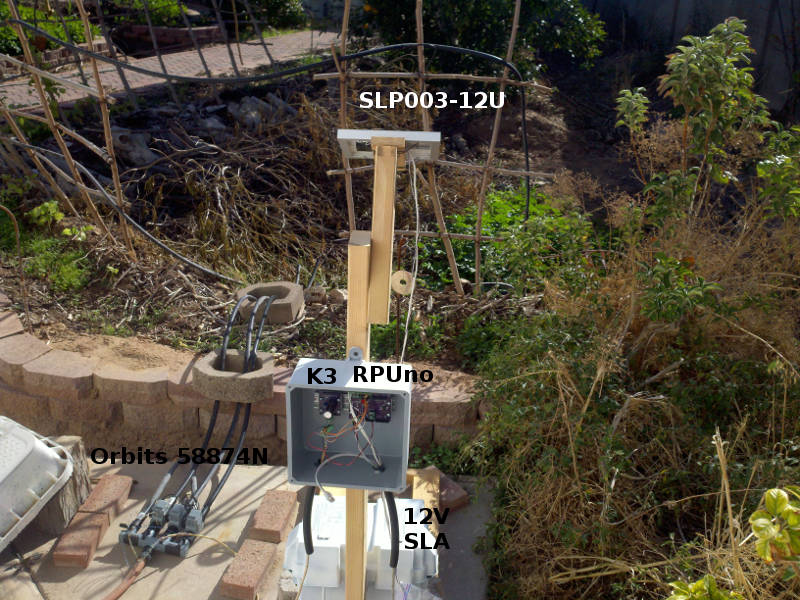
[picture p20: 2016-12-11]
Hardware/Evaluation/RPUno^4+mod_K3^0_wLatchingValves.jpg

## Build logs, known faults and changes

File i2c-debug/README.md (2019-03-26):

# I2C-Debug 

## Overview

2-wire Serial Interface (TWI, a.k.a. I2C) uses pins with SDA and SCL functions. 

Referance datasheet 2-wire Serial Interface. 

Arduino has twi.c and twi.h which was done in C, I did some modification and updates for avr-libc and avr-gcc (4.9). It uses an ASYNC ISR but does block (busy wait) while reading or writing.

## Firmware Upload

With a serial port connection (set the BOOTLOAD_PORT in Makefile) and optiboot installed on the RPUno run 'make bootload' and it should compile and then flash the MCU.

``` 
sudo apt-get install make git gcc-avr binutils-avr gdb-avr avr-libc avrdude
git clone https://github.com/epccs/RPUno/
cd /RPUno/i2c-debug
make bootload
...
avrdude done.  Thank you.
``` 

Now connect with picocom (or ilk).

``` 
#exit picocom with C-a, C-x
picocom -b 38400 /dev/ttyUSB0
``` 

# Commands

Commands are interactive over the serial interface at 38400 baud rate. The echo will start after the second character of a new line. 

## /\[rpu_address\]/\[command \[arg\]\]

rpu_address is taken from the I2C address 0x29 (e.g. get_Rpu_address() which is included form ../lib/rpu_mgr.h). The value of rpu_address is used as a character in a string, which means don't use a null value (C strings are null terminated) as an adddress. The ASCII value for '1' (0x31) is easy and looks nice, though I fear it will cause some confusion when it is discovered that the actual address value is 49.

Commands and their arguments follow.

## /0/id? \[name|desc|avr-gcc\]

identify 

``` 
/0/id?
{"id":{"name":"I2Cdebug^1","desc":"RPUno (14140^9) Board /w atmega328p","avr-gcc":"5.4.0"}}
```

## /0/iscan?

Scan of I2C bus shows all 7 bit devices found. I have a PCA9554 at 0x38 and an 24C02AN eeprom at 0x50.

``` 
/1/iscan?
{"scan":[{"addr":"0x29"},{"addr":"0x38"},{"addr":"0x50"}]}
```

Note: the address does not include the Read/Write bit. 

## /0/iaddr 0..127

Set the I2C address 

``` 
/1/iaddr 56
{"address":"0x38"}
```

Note: Set it with the decimel value, it will return the hex value. This value is used durring read and write, it will also reset the xtBuffer.

## /0/ibuff 0..255\[,0..255\[,0..255\[,0..255\[,0..255\]\]\]\]

Add up to five bytes to I2C transmit buffer. JSON reply is the full buffer. 

``` 
/1/ibuff 3,0
{"txBuffer":["data":"0x3","data":"0x0"]}
``` 

## /0/ibuff?

Show buffer data.

``` 
/1/ibuff?
{"txBuffer":["data":"0x3","data":"0x0"]}
``` 

## /0/iwrite

Attempt to become master and write the txBuffer bytes to I2C address (PCA9554). The txBuffer will clear if write was a success.

``` 
/1/iaddr 56
{"address":"0x38"}
/1/ibuff 3,0
{"txBuffer":["data":"0x3","data":"0x0"]}
/1/iwrite
{"returnCode":"success"}
``` 

## /0/iread? \[1..32\]

If txBuffer has values, attempt to become master and write the byte(s) in buffer (e.g. command byte) to I2C address (example is for a PCA9554) without a stop condition. The txBuffer will clear if write was a success. Then send a repeated Start condition, followed by address and obtain readings into rxBuffer.

``` 
/1/iaddr 56
{"address":"0x38"}
/1/ibuff 3
{"txBuffer":["data":"0x3"}
/1/iread? 1
{"rxBuffer":[{"data":"0xFF"}]}
``` 

Note the PCA9554 has been power cycled in this example, so the reading is the default from register 3.

# PCA9554 Example

Load the PCA9554 configuration register 3 (DDR) with zero to set the port as output. Then alternate register 1 (the output port) with 85 and 170 to toggle its output pins. 

``` 
/1/iaddr 56
{"address":"0x38"}
/1/ibuff 3,0
{"txBuffer":["data":"0x3","data":"0x0"]}
/1/iwrite
{"returnCode":"success"}
/1/ibuff 1,170
{"txBuffer":[{"data":"0x1"},{"data":"0xAA"}]}
/1/iwrite
{"returnCode":"success"}
/1/ibuff 1,85
{"txBuffer":[{"data":"0x1"},{"data":"0x55"}]}
/1/iwrite
{"returnCode":"success"}
``` 

# HTU21D Example 

``` 
/1/scan?
{"scan":[{"addr":"0x29"},{"addr":"0x40"}]}
``` 

Command 0xE3 measures temperature, the clock is streached until data is ready.

``` 
/1/iaddr 64
{"address":"0x40"}
/1/ibuff 227
{"txBuffer":["data":"0xE3"]}
/1/iread? 3
{"rxBuffer":[{"data":"0x6A"},{"data":"0xC"},{"data":"0xC6"}]}
``` 

The first two bytes are the temperature data. The last two bits of LSB are status (ignore or mask them off). Some Python gives the result in deg C.

``` 
Stmp = 0x6A0C
Temp = -46.85 + 175.72 * Stmp / (2**16)
Temp
25.9
``` 

Command 0xE5 measures humidity, again the clock is streached until data is ready.

``` 
/1/iaddr 64
{"address":"0x40"}
/1/ibuff 229
{"txBuffer":["data":"0xE5"]}
/1/read? 3
{"rxBuffer":[{"data":"0x65"},{"data":"0x96"},{"data":"0xBC"}]}
``` 

The first two bytes are the temperature data. The last two bits of LSB are status (ignore or mask them off). Some Python gives the result in deg C.

``` 
Stmp = 0x6596 & 0xFFFC
RH = -6 + 125 * Stmp / (2**16)
RH
43.6
```

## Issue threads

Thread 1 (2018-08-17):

Change Brown-out Detector level to 4.3V

epccs, 2018-08-17:
Extended fuse is set at 0x05 giving a BOD level of 2.7V

Changing extended fuse to 0x04 will give a BOD level of 4.3V

RPUno is not powered with USB so low voltages should trigger the BOD. BOD holds the AVR RESET active (low) during periods of insufficient power supply voltage.

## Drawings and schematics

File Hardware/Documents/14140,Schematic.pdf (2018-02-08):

POWER 7-36V | BLOCKS -40V

## LED TURNS

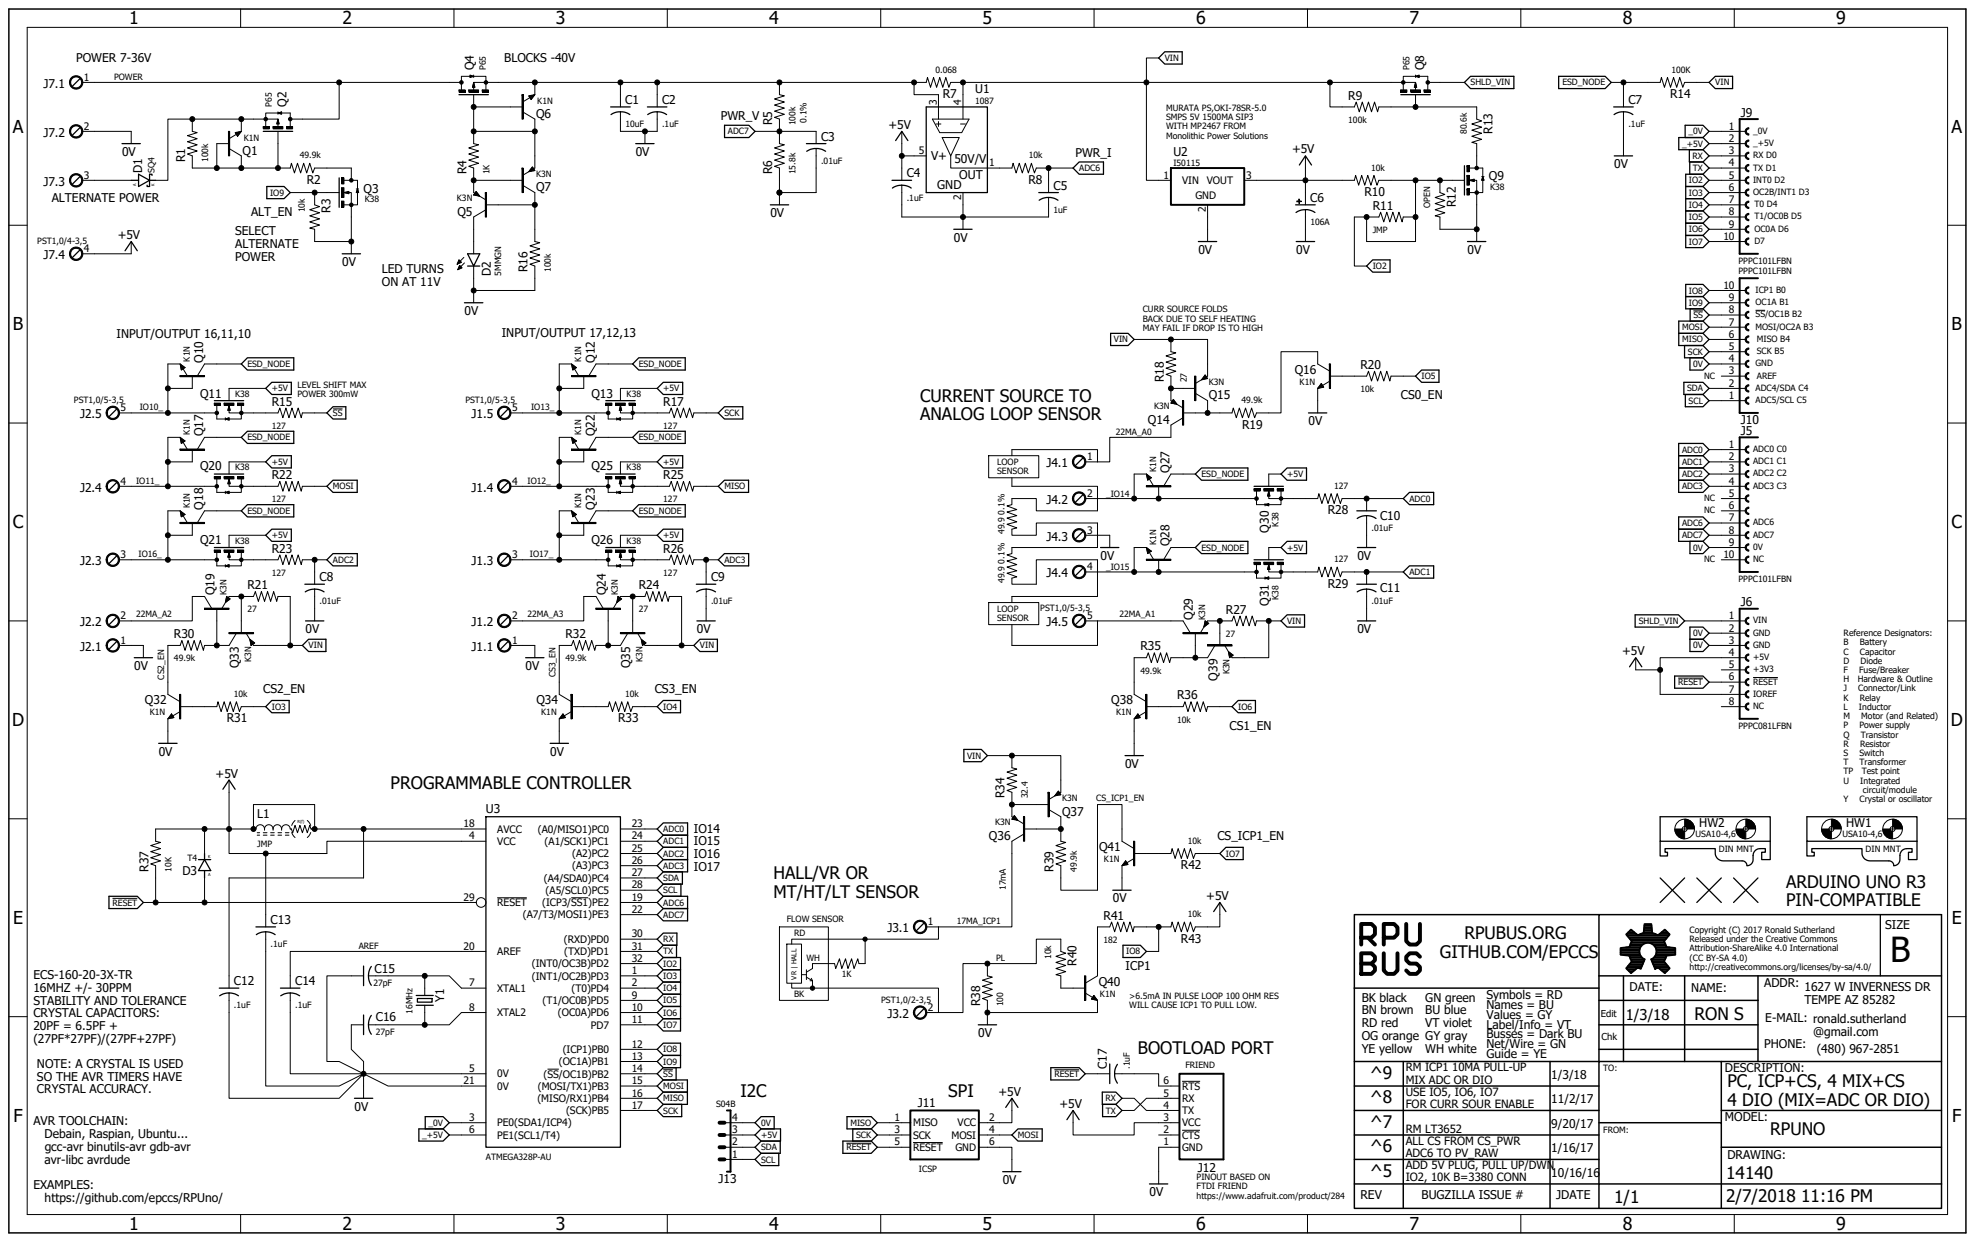
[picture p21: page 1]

CURR SOURCE FOLDS
BACK DUE TO SELF HEATING
MAY FAIL IF DROP IS TO HIGH
VIN

HALL/VR OR
MT/HT/LT SENSOR

Copyright (C) 2017 Ronald Sutherland
Released under the Creative Commons
Attribution-ShareAlike 4.0 International
http://creativecommons.org/licenses/by-sa/4.0/

>6.5mA IN PULSE LOOP 100 OHM RES
WILL CAUSE ICP1 TO PULL LOW.
BOOTLOAD PORT

Edit | 1/3/18 | RON S

Chk

DESCRIPTION:
PC, ICP+CS, 4 MIX+CS
4 DIO (MIX=ADC OR DIO)
MODEL:
RPUNO

SO THE AVR TIMERS HAVE
CRYSTAL ACCURACY.
AVR TOOLCHAIN:
Debain, Raspian, Ubuntu...
gcc-avr binutils-avr gdb-avr
avr-libc avrdude
EXAMPLES:
https://github.com/epccs/RPUno/

^5 | ADD 5V PLUG, PULL UP/DWN IO2, 10K B=3380 CONN | 10/16/16

REV | BUGZILLA ISSUE # | JDATE

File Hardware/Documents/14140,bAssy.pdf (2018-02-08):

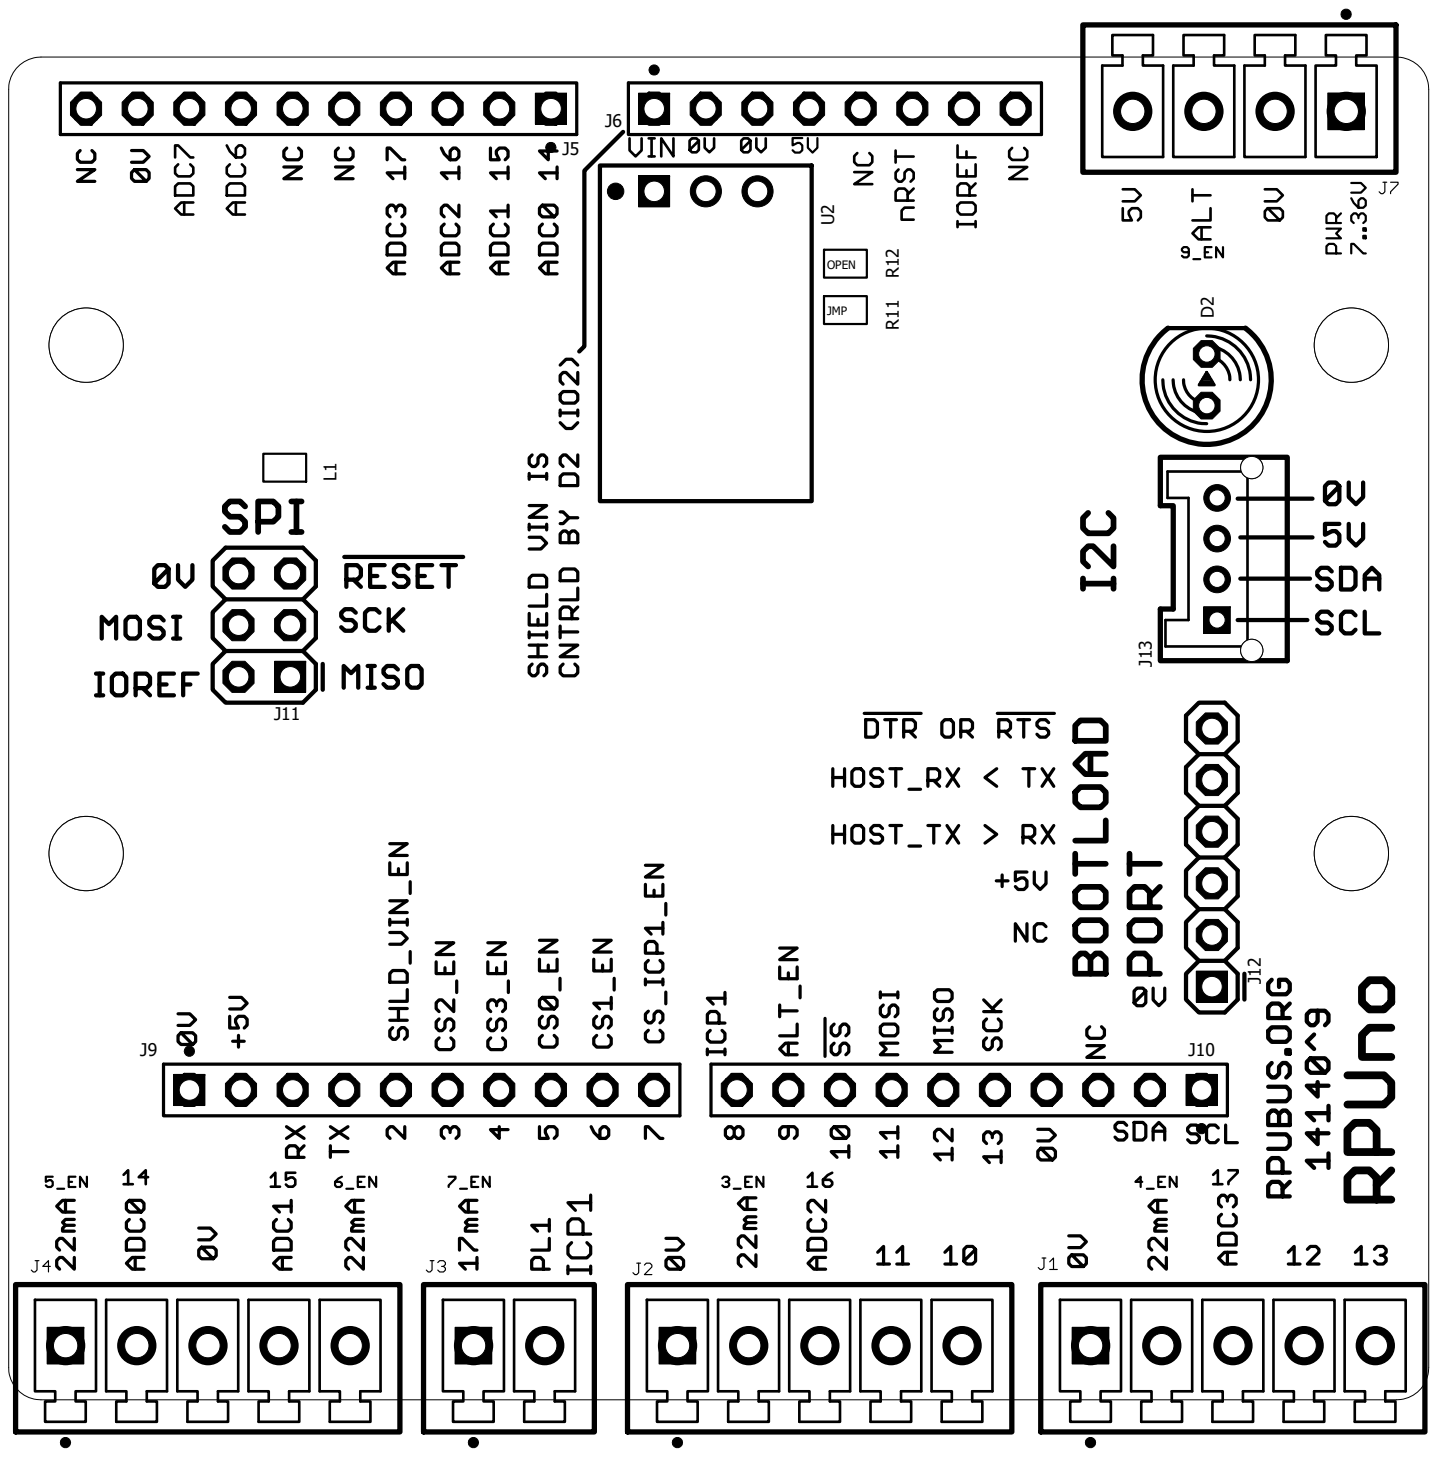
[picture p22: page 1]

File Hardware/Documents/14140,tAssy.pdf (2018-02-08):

C10

C11

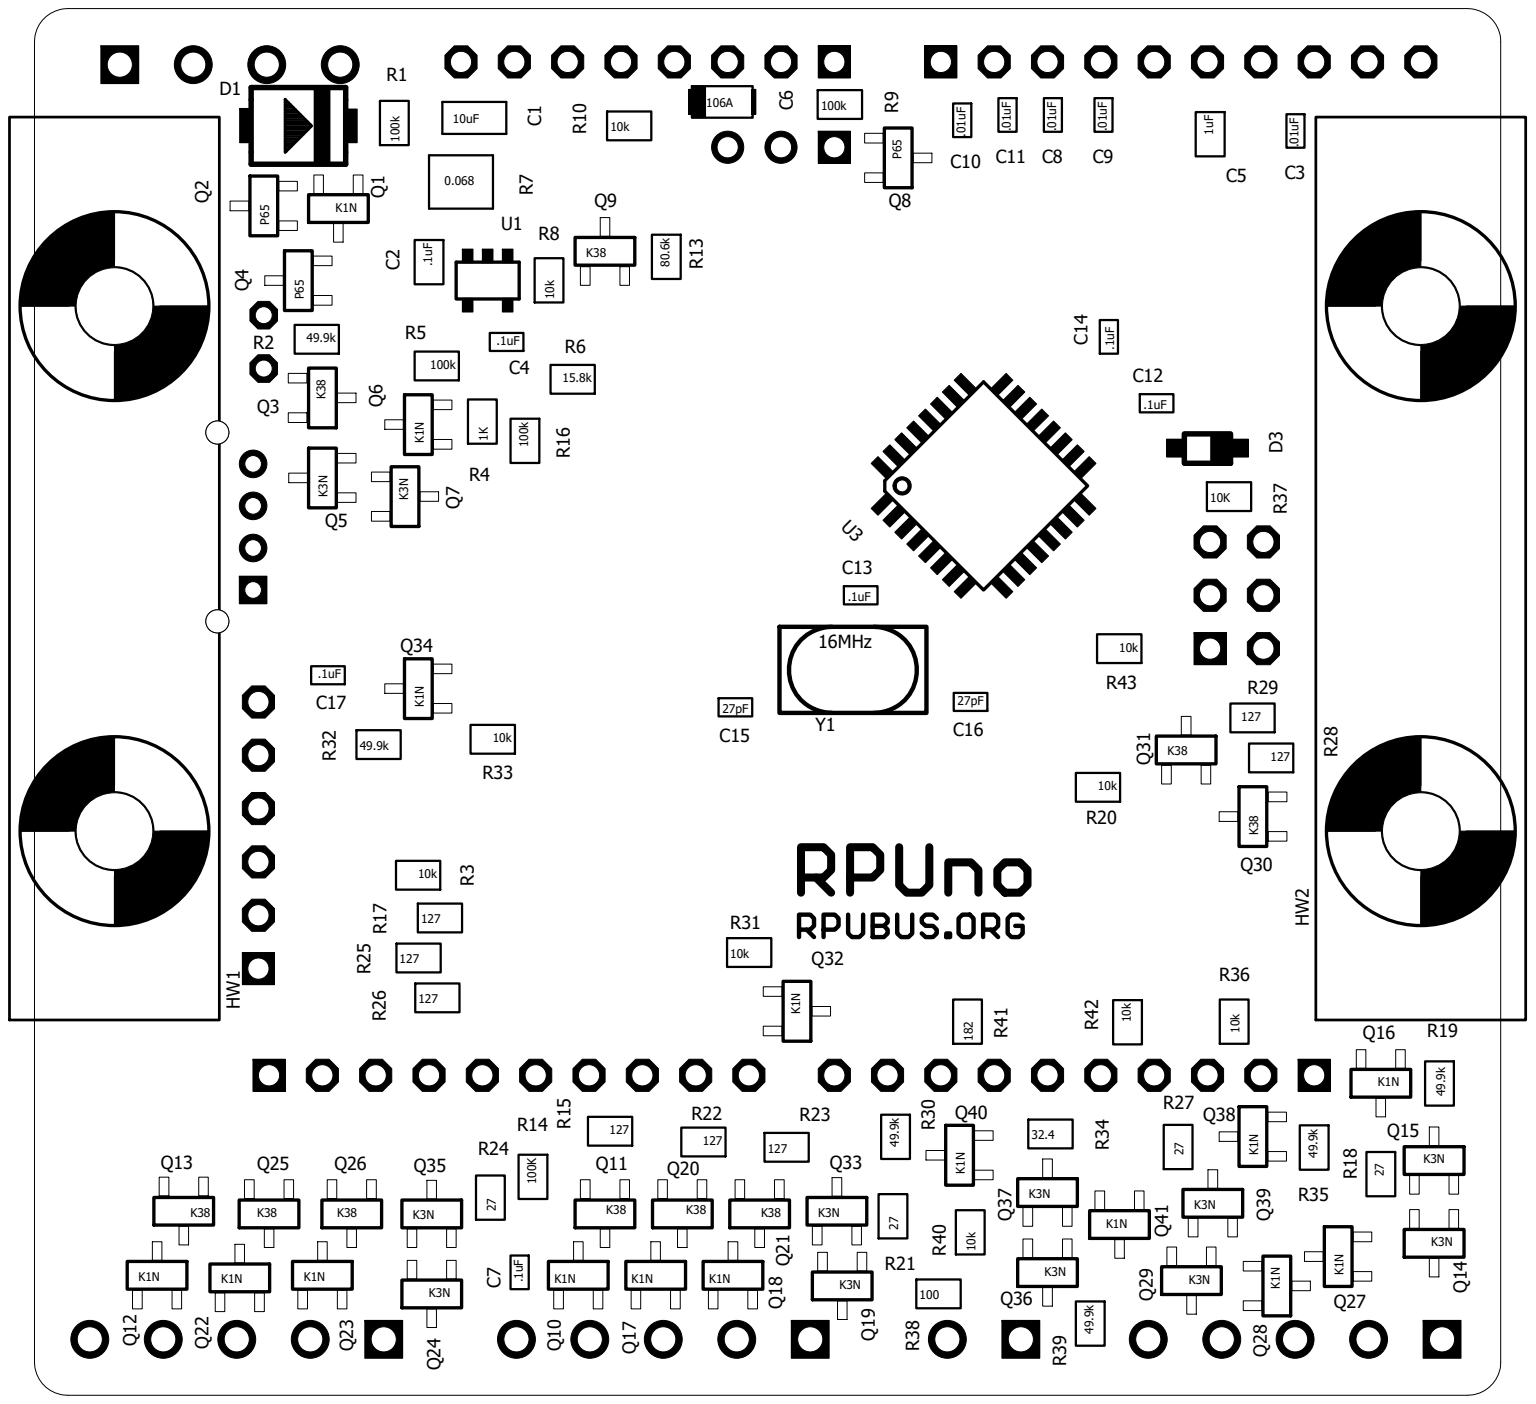
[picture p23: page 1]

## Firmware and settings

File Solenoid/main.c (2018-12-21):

/*
Solenoid is a CLI demonstration for timing latching type devices while measuring a flow meter
Copyright (C) 2016 Ronald Sutherland

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
For a copy of the GNU General Public License use
http://www.gnu.org/licenses/gpl-2.0.html
*/
#include <avr/pgmspace.h>
#include <util/atomic.h>
#include "../lib/uart.h"
#include "../lib/parse.h"
#include "../lib/timers.h"
#include "../lib/adc.h"
#include "../lib/twi.h"
#include "../lib/rpu_mgr.h"
#include "../lib/icp1.h"
#include "../lib/pin_num.h"
#include "../lib/pins_board.h"
#include "../Uart/id.h"
#include "../Adc/analog.h"
#include "../i2c-debug/i2c-scan.h"
#include "../i2c-debug/i2c-cmd.h"
#include "../DayNight/day_night.h"
#include "../AmpHr/chrg_accum.h"
#include "../Alternat/alternat.h"
#include "../Capture/capture.h"
#include "solenoid.h"

#define ADC_DELAY_MILSEC 100UL
static unsigned long adc_started_at;

#define STATUS_LED DIO13

#define DAYNIGHT_STATUS_LED DIO17
#define DAYNIGHT_BLINK 500UL
static unsigned long day_status_blink_started_at;

#define BLINK_DELAY 1000UL
static unsigned long blink_started_at;
static unsigned long blink_delay;
static char rpu_addr;
static uint8_t solenoids_initalized;

void ProcessCmd()
{ 
    if (solenoids_initalized) 
    {
        if ( (strcmp_P( command, PSTR("/id?")) == 0) && ( (arg_count == 0) || (arg_count == 1)) )
        {
            Id("Solenoid"); // ../Uart/id.c
        }
        if ( (strcmp_P( command, PSTR("/kpre")) == 0) && ( (arg_count == 2 ) ) )
        {
            KDelayStart(); // solenoid.c
        }
        if ( (strcmp_P( command, PSTR("/krunt")) == 0) && ( (arg_count == 2 ) ) )
        {
            KRunTime(); // solenoid.c
        }
        if ( (strcmp_P( command, PSTR("/kdelay")) == 0) && ( (arg_count == 2 ) ) )
        {
            KDelay(); // solenoid.c
        }
        if ( (strcmp_P( command, PSTR("/kfstop")) == 0) && ( (arg_count == 2 ) ) )
        {
            KFlowStop(); // solenoid.c
        }
        if ( (strcmp_P( command, PSTR("/krun")) == 0) && ( (arg_count == 1) || (arg_count == 2) ) )
        {
            KRun(); // solenoid.c
        }
        if ( (strcmp_P( command, PSTR("/ksave")) == 0) && ( (arg_count == 2 ) ) )
        {
            KSave(); // solenoid.c
        }
        if ( (strcmp_P( command, PSTR("/kload")) == 0) && ( (arg_count == 1 ) ) )
        {
            KLoad(); // solenoid.c
        }
        if ( (strcmp_P( command, PSTR("/ktime?")) == 0) && ( (arg_count == 1 ) ) )
        {
            KTime(); // solenoid.c
        }
        if ( (strcmp_P( command, PSTR("/kflow?")) == 0) && ( (arg_count == 1 ) ) )
        {
            KFlow(); // solenoid.c
        }
        if ( (strcmp_P( command, PSTR("/kstop")) == 0) && ( (arg_count == 1 ) ) )
        {
            KStop(); // solenoid.c
        }
        if ( (strcmp_P( command, PSTR("/analog?")) == 0) && ( (arg_count >= 1 ) && (arg_count <= 5) ) )
        {
            Analog(20000UL); // ../Adc/analog.c: show every 20 sec until terminated
        }
        if ( (strcmp_P( command, PSTR("/iscan?")) == 0) && (arg_count == 0) )
        {
            I2c_scan(); // ../i2c-debug/i2c-scan.c
        }
        if ( (strcmp_P( command, PSTR("/iaddr")) == 0) && (arg_count == 1) )
        {
            I2c_address(); // ../i2c-debug/i2c-cmd.c
        }
        if ( (strcmp_P( command, PSTR("/ibuff")) == 0) )
        {
            I2c_txBuffer(); // ../i2c-debug/i2c-cmd.c
        }
        if ( (strcmp_P( command, PSTR("/ibuff?")) == 0) && (arg_count == 0) )
        {
            I2c_txBuffer(); // ../i2c-debug/i2c-cmd.c
        }
        if ( (strcmp_P( command, PSTR("/iwrite")) == 0) && (arg_count == 0) )
        {
            I2c_write(); // ../i2c-debug/i2c-cmd.c
        }
        if ( (strcmp_P( command, PSTR("/iread?")) == 0) && (arg_count == 1) )
        {
            I2c_read(); // ../i2c-debug/i2c-cmd.c
        }
        if ( (strcmp_P( command, PSTR("/day?")) == 0) && ( (arg_count == 0 ) ) )
        {
            Day(60000UL); // ../DayNight/day_night.c: show every 60 sec until terminated
        }
        if ( (strcmp_P( command, PSTR("/charge?")) == 0) && ( (arg_count == 0 ) ) )
        {
            Charge(60000UL); // ../AmpHr/chrg_accum.c: show every 60 sec until terminated
        }
        if ( (strcmp_P( command, PSTR("/alt")) == 0) && ( (arg_count == 0 ) ) )
        {
            EnableAlt(); // ../Alternat/alternat.c
        }
        if ( (strcmp_P( command, PSTR("/altcnt?")) == 0) && ( (arg_count == 0 ) ) )
        {
            AltCount(); // ../Alternat/alternat.c
        }
        if ( (strcmp_P( command, PSTR("/count?")) == 0) &&  ( (arg_count == 0) || ( (arg_count == 1) && (strcmp_P( arg[0], PSTR("icp1")) == 0) ) ) )
        {
            Count(); // ../Capture/capture.c
        }
        if ( (strcmp_P( command, PSTR("/capture?")) == 0) && ( (arg_count == 0 ) || ( (arg_count == 2) && (strcmp_P( arg[0], PSTR("icp1")) == 0) ) ) )
        {
            Capture(); // ../Capture/capture.c
        }
        if ( (strcmp_P( command, PSTR("/event?")) == 0) && ( (arg_count == 0 ) || ( (arg_count == 2) && (strcmp_P( arg[0], PSTR("icp1")) == 0) ) ) )
        {
            Event(); // ../Capture/capture.c
        }
        if ( (strcmp_P( command, PSTR("/initICP")) == 0) && ( ( (arg_count == 3) && (strcmp_P( arg[0], PSTR("icp1")) == 0) ) ) )
        {
            InitICP(); // ../Capture/capture.c
        }
    }
    else
    {
        if (! solenoids_initalized)
        {
            printf_P(PSTR("{\"err\":\"NotFinishKinit\"}\r\n"));
        }
        initCommandBuffer();
        return;
    }
}

//At start of each night 
void callback_for_night_attach(void)
{
    //turn off alternat power input
    alt_enable = 0;
    
    // turn off the Solenoid's
    for (uint8_t solenoid = 1; solenoid <= SOLENOID_COUNT; solenoid++)
    {
        StopK(solenoid);
    }
}

//At start of each day.
void callback_for_day_attach(void)
{
    alt_enable = 1; //turn on alternat power input
    alt_count = 0; // this value is used to tell if the battery got a full charge

    // setup AmpHr accumulators and load Adc calibration reference
    if (!init_ChargAccumulation(PWR_I)) // ../AmpHr/chrg_accum.c
    {
        blink_delay = BLINK_DELAY/4;
    }

    for(uint8_t solenoid = 1; solenoid <= SOLENOID_COUNT; solenoid++)
    {
        // load the solenoid control settings from EEPROM
        LoadKControlFromEEPROM(solenoid);
        // operate them
        StartK(solenoid);
    }
}

void setup(void) 
{
    pinMode(STATUS_LED,OUTPUT);
    digitalWrite(STATUS_LED,LOW);

    pinMode(DAYNIGHT_STATUS_LED,OUTPUT);
    digitalWrite(DAYNIGHT_STATUS_LED,HIGH);

    pinMode(ALT_EN,OUTPUT);
    digitalWrite(ALT_EN,LOW);

    pinMode(CS_ICP1_EN,OUTPUT);
    digitalWrite(CS_ICP1_EN,HIGH);

    // Initialize Timers, ADC, and clear bootloader, Arduino does these with init() in wiring.c
    initTimers(); //Timer0 Fast PWM mode, Timer1 & Timer2 Phase Correct PWM mode.
    init_ADC_single_conversion(EXTERNAL_AVCC); // warning AREF must not be connected to anything
    init_uart0_after_bootloader(); // bootloader may have the UART setup

    // put ADC in Auto Trigger mode and fetch an array of channels
    enable_ADC_auto_conversion(BURST_MODE);
    adc_started_at = millis();

    /* Initialize Input Capture Unit (see ../lib/icp1.h) */
    initIcp1(TRACK_RISING, ICP1_MCUDIV64) ;

    /* Initialize UART, it returns a pointer to FILE so redirect of stdin and stdout works*/
    stdout = stdin = uartstream0_init(BAUD);

    /* Initialize I2C. note: I2C scan will stop without a pull-up on the bus */
    twi_init(TWI_PULLUP);

    /* Clear and setup the command buffer, (probably not needed at this point) */
    initCommandBuffer();

    // Enable global interrupts to start TIMER0 and UART ISR's
    sei(); 

    blink_started_at = millis();
    day_status_blink_started_at = millis();

    rpu_addr = get_Rpu_address();
    blink_delay = BLINK_DELAY;

    // blink fast if a default address from RPU manager not found
    if (rpu_addr == 0)
    {
        rpu_addr = '0';
        blink_delay = BLINK_DELAY/4;
    }

    // setup solenoid control
    init_K();

    // solenoids may have been previously latched so this
    // loads settings that will run a quick cycle to home the hardware
    Reset_All_K();
    solenoids_initalized = 0;

    // register callbacks for DayNight events
    Night_AttachWork(callback_for_night_attach);
    Day_AttachWork(callback_for_day_attach);

    // setup AmpHr accumulators
    if (!init_ChargAccumulation(PWR_I)) // ../AmpHr/chrg_accum.c
    {
        blink_delay = BLINK_DELAY/4;
    }

    // default debounce is 15 min (e.g. 900,000 millis)
    evening_debouce = 1200000UL; // 20 min
    morning_debouce = 1200000UL;
    // analog reading of 5*5.0/1024.0 is about 0.024V
    // analog reading of 10*5.0/1024.0 is about 0.049V
    // analog reading of 20*5.0/1024.0 is about 0.098V
    evening_threshold = 10; // SLP003 with 10k and 100k divider
    morning_threshold = 20;

    alt_count = 0;
}

void blink(void)
{
    unsigned long kRuntime = millis() - blink_started_at;
    if ( kRuntime > blink_delay)
    {
        digitalToggle(STATUS_LED);
        
        // next toggle 
        blink_started_at += blink_delay; 
    }
}

void blink_day_status(void)
{
    unsigned long kRuntime = millis() - day_status_blink_started_at;
    uint8_t state = DayState();
    if ( ( (state == DAYNIGHT_EVENING_DEBOUNCE_STATE) || \
           (state == DAYNIGHT_MORNING_DEBOUNCE_STATE) ) && \
           (kRuntime > (DAYNIGHT_BLINK/2) ) )
    {
        digitalToggle(DAYNIGHT_STATUS_LED);
        
        // set for next toggle 
        day_status_blink_started_at += DAYNIGHT_BLINK/2; 
    }
    if ( ( (state == DAYNIGHT_DAY_STATE) ) && \
           (kRuntime > (DAYNIGHT_BLINK) ) )
    {
        digitalWrite(DAYNIGHT_STATUS_LED,HIGH);
        
        // set for next toggle 
        day_status_blink_started_at += DAYNIGHT_BLINK; 
    }
    if ( ( (state == DAYNIGHT_NIGHT_STATE) ) && \
           (kRuntime > (DAYNIGHT_BLINK) ) )
    {
        digitalWrite(DAYNIGHT_STATUS_LED,LOW);
        
        // set for next toggle 
        day_status_blink_started_at += DAYNIGHT_BLINK; 
    }
    if ( ( (state == DAYNIGHT_FAIL_STATE) ) && \
           (kRuntime > (DAYNIGHT_BLINK/8) ) )
    {
        digitalToggle(DAYNIGHT_STATUS_LED);
        
        // set for next toggle 
        day_status_blink_started_at += DAYNIGHT_BLINK/8; 
    }
}

uint8_t adc_burst(void)
{
    unsigned long kRuntime= millis() - adc_started_at;
    if ((kRuntime) > ((unsigned long)ADC_DELAY_MILSEC))
    {
        enable_ADC_auto_conversion(BURST_MODE);
        adc_started_at += ADC_DELAY_MILSEC; 
        return 1;
    } 
    else
    {
        return 0;
    }
}

int main(void) 
{
    setup();

    while(1) 
    { 
        // use STATUS_LED to show if I2C has a bus manager
        blink();
        
        // use DAYNIGHT_STATUS_LED to show day_state
        blink_day_status();

        // Check Day Light is a function that operates a day-night state machine.
        CheckDayLight(ADC2); // ../DayNight/day_night.c

        // delay between ADC burst
        if ( adc_burst() )
        {
            check_if_alt_should_be_on(PWR_V, 115.8/15.8, 13.6);
        }

        // check how much charge went into battery
        CheckChrgAccumulation(PWR_I);

        // check if character is available to assemble a command, e.g. non-blocking
        if ( (!command_done) && uart0_available() ) // command_done is an extern from parse.h
        {
            // get a character from stdin and use it to assemble a command
            AssembleCommand(getchar());

            // address is an ascii value, warning: a null address would terminate the command string. 
            StartEchoWhenAddressed(rpu_addr);
        }
        
        // check if a character is available, and if so flush transmit buffer and nuke the command in process.
        // A multi-drop bus can have another device start transmitting after getting an address byte so
        // the first byte is used as a warning, it is the onlly chance to detect a possible collision.
        if ( command_done && uart0_available() )
        {
            // dump the transmit buffer to limit a collision 
            uart0_flush(); 
            initCommandBuffer();
        }
        
        // finish echo of the command line befor starting a reply (or the next part of a reply)
        if ( command_done && (uart0_availableForWrite() == UART_TX0_BUFFER_SIZE) )
        {
            if ( !echo_on  )
            { // this happons when the address did not match 
                initCommandBuffer();
            }
            else
            {
                if (command_done == 1)  
                {
                    findCommand();
                    command_done = 10;
                }
                
                // do not overfill the serial buffer since that blocks looping, e.g. process a command in 32 byte chunks
                if ( (command_done >= 10) && (command_done < 250) )
                {
                     ProcessCmd();
                }
                else 
                {
                    initCommandBuffer();
                }
            }
        }
        
        // Solenoid Control is a function that moves them through different states that are timed with millis() or icp1 flow count.
        KControl();
        
        if (!solenoids_initalized)
        {
            // lets test if they are in use.
            uint8_t solenoids_in_use = 0;
            for(uint8_t solenoid = 1; solenoid <= SOLENOID_COUNT; solenoid++)
            {
                if (KLive(solenoid))
                {
                    solenoids_in_use =1;
                    break;
                }
            }
            if (! solenoids_in_use) 
            {
                solenoids_initalized = 1;
            }
        }
    }        
    return 0;
}

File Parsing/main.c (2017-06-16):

/*
Demonstration of serial Parsing for textual commands and arguments.
Copyright (C) 2016 Ronald Sutherland

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
For a copy of the GNU General Public License use
http://www.gnu.org/licenses/gpl-2.0.html 
*/
#include <avr/pgmspace.h>
#include <util/atomic.h>
#include "../lib/uart.h"
#include "../lib/parse.h"
#include "../lib/twi.h"
#include "../lib/rpu_mgr.h"

static char rpu_addr;

int main(void) {    

    /* Initialize UART, it returns a pointer to FILE so redirect of stdin and stdout works*/
    stdout = stdin = uartstream0_init(BAUD);
    initCommandBuffer();

    /* Initialize I2C, with the internal pull-up*/
    twi_init(TWI_PULLUP);

    sei(); // Enable global interrupts starts the UART

    // RPUftdi, RPUadpt, RPUpi have a bus manager with our bus addrss.
    rpu_addr = get_Rpu_address();

    // if the adddress fails to read then the bus manager will disconnect after time is given for bootload
    if (rpu_addr == 0)
    {
        printf_P(PSTR("{\"err\":\"I2Cbad_UseAddr=0\"}\r\n"));
        rpu_addr = '0'; // default allows it to work without a shield
    }

    // non-blocking code in loop
    while(1) 
    {
        // check if character is available to assemble a command, e.g. non-blocking
        if ( (!command_done) && uart0_available() ) // command_done is an extern from parse.h
        {
            // get a character from stdin and use it to assemble a command
            AssembleCommand(getchar());

            // address is the ascii value for '0' note: a null address will terminate the command string. 
            StartEchoWhenAddressed(rpu_addr);
        }
        
        // check if the character is available, and if so stop transmit and the command in process.
        // a multi-drop bus can have another device start transmitting after the second received byte so
        // there is little time to detect a possible collision
        if ( command_done && uart0_available() )
        {
            // dump the transmit buffer to limit a collision 
            uart0_flush(); 
            initCommandBuffer();
        }
        
        // finish echo of the command line befor starting a reply (or the next part of reply), also non-blocking.
        if ( command_done && (uart0_availableForWrite() == UART_TX0_BUFFER_SIZE) )
        {
            if ( !echo_on  )
            { // this happons when the address did not match
                initCommandBuffer();
            }
            else
            {
                // command is a pointer to string and arg[] is an array of pointers to strings
                // use findCommand to make them point to the correct places in the command line
                // this can only be done once, since spaces and delimeters are replaced with null termination
                if (command_done == 1)  
                {
                    findCommand();
                    command_done = 2;
                }
                if (command_done == 2)
                {
                    if (command != '\0' )
                    {
                        printf_P(PSTR("{\"cmd\": \"%s\"}\r\n"),command);
                        command_done = 3;
                    }
                    else
                    {
                        initCommandBuffer();
                    }
                }
                if (command_done == 3)
                {
                    printf_P(PSTR("{\"arg_count\": \"%d\"}\r\n"),arg_count);
                    if (arg_count > 0)
                    {
                        command_done = 4;
                    }
                    else
                    {
                        initCommandBuffer();
                    }
                }
                if (command_done == 4)
                {
                    printf_P(PSTR("{\"arg[0]\": \"%s\"}\r\n"),arg[0]);
                    if (arg_count > 1)
                    {
                        command_done = 5;
                    }
                    else
                    {
                        initCommandBuffer();
                    }
                }
                if (command_done == 5)
                {
                    printf_P(PSTR("{\"arg[1]\": \"%s\"}\r\n"),arg[1]);
                    if (arg_count > 2)
                    {
                        command_done = 6;
                    }
                    else
                    {
                        initCommandBuffer();
                    }
                }
                if (command_done == 6)
                {
                    printf_P(PSTR("{\"arg[2]\": \"%s\"}\r\n"),arg[2]);
                    if (arg_count > 3)
                    {
                        command_done = 7;
                    }
                    else
                    {
                        initCommandBuffer();
                    }
                }
                if (command_done == 7)
                {
                    printf_P(PSTR("{\"arg[3]\": \"%s\"}\r\n"),arg[3]);
                    if (arg_count > 4)
                    {
                        command_done = 8;
                    }
                    else
                    {
                        initCommandBuffer();
                    }
                }
                if (command_done == 8)
                {
                    printf_P(PSTR("{\"arg[4]\": \"%s\"}\r\n"),arg[4]);
                    initCommandBuffer();
                }
            }
         }
    }        
    return 0;
}

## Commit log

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2016-04-27 fix parsing logic and debug msgs
    [main.c]
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2016-05-26 many updates
    add Eeprom, use id.c in Uart for other applications, this shows how
    Makefiles can be used to develop and test the modular parts of a
    interactive command interface.
2016-05-30 analog and capture updates
    adc auto trigger reads channels and then needs started again. Capture
    adds /event? cmd and removes a large atomic code block.
2016-06-05 Capture: prevent high/low capture
    unless mode is to track both edges
2016-06-09 Uart: fix some notes befor copy to Irrigate7
2016-06-16 Ht: for data loging an HT with the onboard adc connections to solar power.
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2016-07-10 i2c-debug: makefile setup clean out ino files
    also reduce fuse setting duplication, and fix IO function names
    [i2c-cmd.c, main.c, reflow.c]
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2016-11-15 add hardware files
    [14140,BOM.csv, 14140.brd, 14140.sch]
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2016-11-19 i2c-debug: blink fast if rpu mgr not found on i2c, and use the rpu_addr
    ouch found it... I was not passing the rpu_addr to
    StartEchoWhenAddressed()
2016-11-20 Adc: ch7 can now read PWR (e.g. battery)
    up to 15V (was 7.5V for 6V SLA)
    [14140,BOM.csv, 14140.brd, 14140.sch]
2016-11-22 Digital: Wiring like digital control bridge
    [MultiDrop.sch]
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2016-12-01 Hardware: evaluation and testing and reorg
    form epccs.org pages
    [14140,BOM.csv, 14140.brd, 14140.sch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]
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2016-12-05 Eeprom: add uint16 and uint32 for use with solenoid
    [14140.sch]
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2016-12-06 Solenoid: add cmd's /time, /flow, /stop
    , and flow_stop is /fstop cmd.
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2016-12-13 Solenoid: add day-night state machine to load from eeprom at start of day
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2017-01-18 Hardware: ^6 review
    [14140.brd, 14140.sch]
2017-01-21 baud rate 38400 has .2% error 115200 has 2.1% error
    [main.c]
2017-01-24 Hardware: bom and baud rate notes
    [14140,BOM.csv]
2017-01-24 Hardware: evaluation pwr mgt with RPUpi ^1 shield
    [MultiDrop.sch]
2017-02-18 SelfTest: not done yet but a good save point
    [14140.brd, 14140.sch, SelfTestWiring.sch]
2017-03-23 Hardware: rm the 10k b=3380 thermistor
    [14140,BOM.csv]
2017-04-21 Hardware: circuit node names for bat-discon and vin-discon
    [14140.brd, 14140.sch]
2017-04-23 Hardware: flow sensor info on schematic
    [14140.sch]
2017-04-25 Hardware: note on schematic about battery disconnect
    [14140.sch]
2017-05-12 AmpHr: framework to measure solar power
    [14140,BOM.csv]
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2017-05-14 AmpHr: one command shows charge and discharge accumulation
    from start of day
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2017-05-21 Bootloader: setup to build from source
    [14140,BOM.csv]
2017-05-23 Hardware: crystal capacitors, eagle is not for open hardware
    [14140,BOM.csv, 14140.brd, 14140.sch]
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2017-07-18 NightLight: somewhat working, need to remove capture and add AmpHr
    [NightLightWiring.sch]
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2017-08-13 DayNight: skip work callback if nothing got registered
    [day_night.c, i2c-cmd.c]
2017-08-23 SpiSlv: evaluation done, it works at 500kHz
    [SpiSlvWiring.sch]
2017-09-02 NightLight: evaluation
    100 Ohm added to status led
    [NightLightWiring.sch]
2017-09-26 Hardware: ^7 review, removed LT3652
    [14140,BOM.csv, 14140^6.brd, 14140^6.sch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]
2017-09-26 Hardware: ^7 reviewing
    [14140,BOM.csv]
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2017-10-21 Hardware: ^7 testing
    [14140,BOM.csv, 14140DIN,BOM.csv, 14140HDR,BOM.csv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]
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2017-10-27 Reflow: setup for ^7 to use reflow oven
    [ReflowWiring.sch]
2017-11-05 Hardware: ^8 update
    [14140HDR,BOM.csv, 14140PLUG,BOM.csv, 14140SMD,BOM.csv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]
2017-11-08 Hardware: ^8 boms
    [14140BRD,BOM.csv, 14140DIN,BOM.csv, 14140HDR,BOM.csv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]
2017-11-18 Hardware: ^8 review
    [14140BRD,BOM.csv, 14140DIN,BOM.csv, 14140HDR,BOM.csv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]
2017-12-13 Bootloader: updates for avr-gcc 5.4.0+Atmel3.6.0 and avrdude 6.3
    [14140PLUG,BOM.csv]
2017-12-15 ^8 Testing done, 1v1 band-gap found in self-test which puts in eeprom
    [14140SMD,BOM.csv]
2018-01-25 Hardware: ^9 rdy for review
    [14140HDR,BOM.csv, 14140SMD,BOM.csv, MultiDrop.sch]
2018-02-08 Hardware: PWR_I sense, SHLD_VIN gate stress
    [14140SMD,BOM.csv, MultiDrop.sch]
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2018-04-24 SelfTest: update for ^9
    [14140SMD,BOM.csv, SelfTestWiring.sch]
2018-04-26 SpiSlv: changes for ^9
    [SpiSlvWiring.sch]
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2018-05-09 NightLight: ^9 updates
    [NightLightWiring.sch]
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2018-05-17 Reflow: ^9 updates and add a light sensor to start profile
    [NightLightWiring.sch, ReflowWiring.sch]
2018-05-17 Solenoid: ^9 updates (needs testing)
    [SolenoidWiring.sch]
2018-05-17 Solenoid: wiring show flow sensor
    [NightLightWiring.sch, ReflowWiring.sch, SolenoidWiring.sch]
2018-05-22 Hardware: tested two boards to list on tindie
    [MultiDrop.sch]
2018-05-27 Alternat: charge a battery with solar power
    [14140BRD,BOM.csv, AuxilaryWiring.sch]
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2018-06-03 NightLight: add alternate power input for solar panel
    bug noted in readme
    [NightLightWiring.sch]
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2018-06-07 Hardware: ^9 evaluation with Solenoid setup
    github or TortoiseHg have changed so I expect to see a lot of LF to CRLF in updates
2018-06-09 KNL: combine NightLight with Solenoid and squeeze.
    [KNLWiring.sch]
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2018-09-03 Hardware: BOM's for din-header-plug on ^9 got a look
    [14140DIN,BOM.csv, 14140HDR,BOM.csv, 14140PLUG,BOM.csv]
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2018-12-10 DayNight: add sensor wiring
    [LightSensorWiring.sch]
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2018-12-21 Solenoid: voltage divider on SLP003 solar pannel for light sensor
    [AuxilaryWiring.sch]
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2019-03-19 SpiSlv: remove ADC2 notes
    [SpiSlvWiring.sch]
2019-03-22 libraries pin related need correct license
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2019-05-17 Bootloader: toolchain notes
    [14140HDR,BOM.csv]
2019-06-03 uart glitch at init, optiboot does not glitch so do what it does.
2019-06-23 XcvrTest: wip, putting ideas in place
    [XcvrTestWiring.sch]
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2019-08-05 Bootloader: with linuxspi set fuse and load image with the one rule

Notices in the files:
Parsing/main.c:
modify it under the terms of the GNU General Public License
